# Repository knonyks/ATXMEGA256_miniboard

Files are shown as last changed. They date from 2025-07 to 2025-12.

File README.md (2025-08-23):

# ONYKS ATXMEGA256 Miniboard
Miniboard to prosta płytka deweloperska stworzona dla mikrokontrolera ATXMEGA256 przez KN ONYKS. Płytka zawiera możliwie minimalną liczbę elementów potrzebnych do zaczęcia programowania tego mikrokontrolera aby użytkownik miał pełną kontrolę nad swoim projektem.

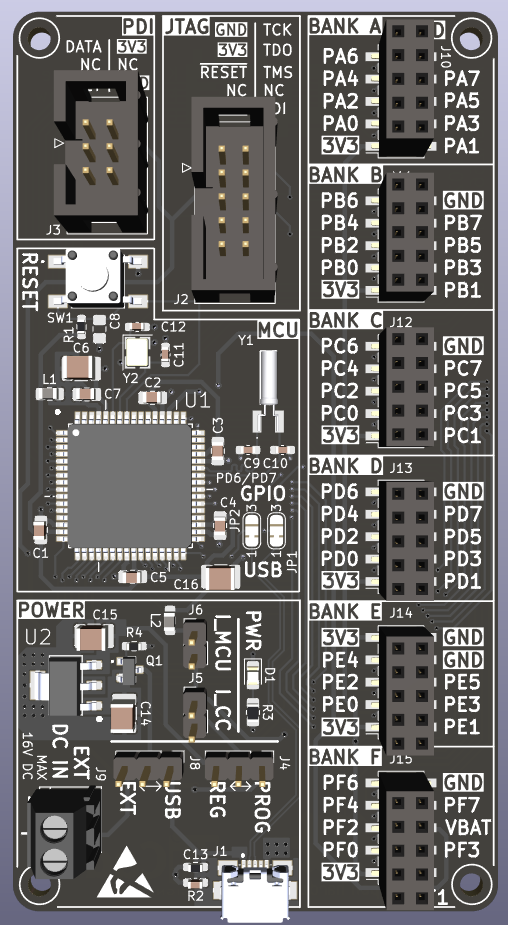
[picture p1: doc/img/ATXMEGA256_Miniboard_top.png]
Top

<br>
<br>
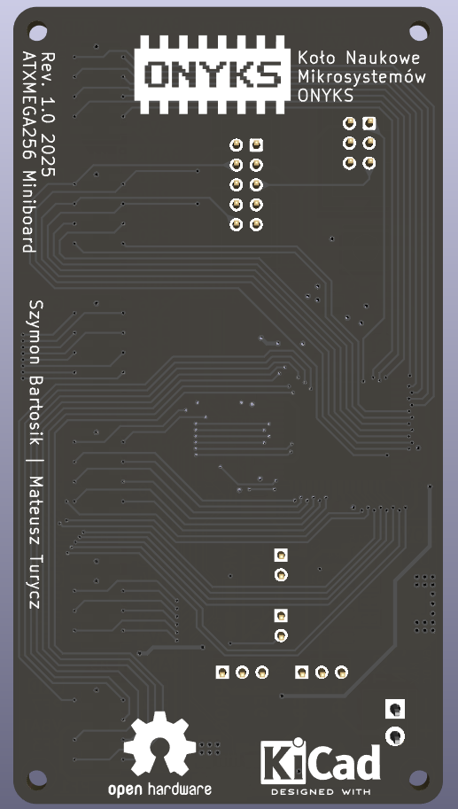
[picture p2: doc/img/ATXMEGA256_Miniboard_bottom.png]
Bottom


## TODO

- [x] Schemat połączeń MCU
- [x] Schemat sekcji zasilania
- [x] PCB
- [x] Dokumentacja - schematy, PCB, zdjęcia
- [ ] Dokumentacja - instrukcja obsługi
- [x] Dokumentacja - BOM
- [ ] Toolchain
- [x] Modele 3D
- [ ] Rysunek techniczny (poglądowy)

## Autorzy
Szymon Bartosik, Mateusz Turycz

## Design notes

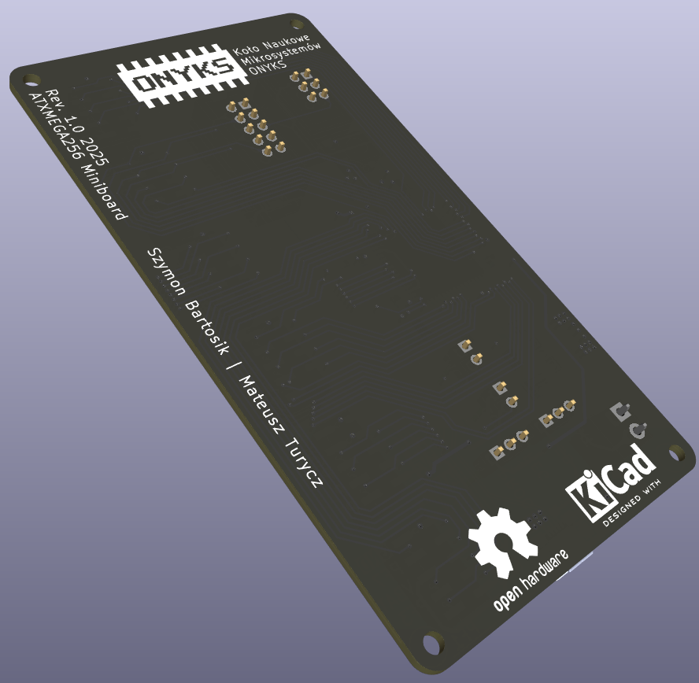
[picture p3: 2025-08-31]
doc/img/ATXMEGA256_Miniboard_bottom2.png

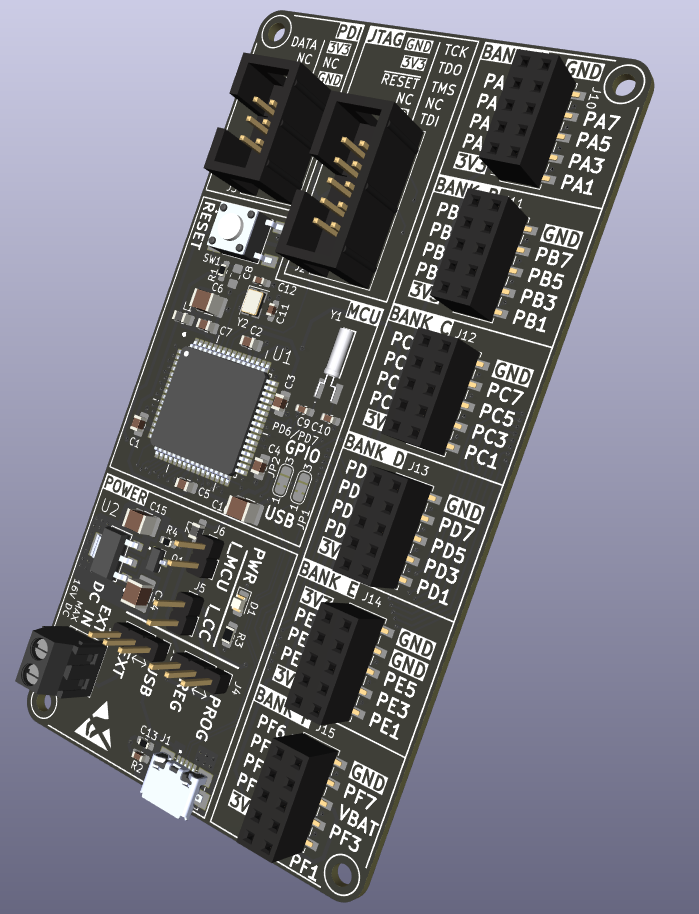
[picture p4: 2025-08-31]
doc/img/ATXMEGA256_Miniboard_top3.png

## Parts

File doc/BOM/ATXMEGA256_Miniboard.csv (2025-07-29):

Reference | Qty | Value | DNP | Footprint | Package | Part Number | Manufacturer
C1,C2,C3,C4,C5,C7,C8 | 7 | 100n | DNP | Capacitor_SMD:C_0805_2012Metric_Pad1.18x1.45mm_HandSolder | 0805 | C0805C104J4RACTU | KEMET
C6,C14,C15,C16 | 4 | 10u |  | Capacitor_SMD:C_1210_3225Metric_Pad1.33x2.70mm_HandSolder | 1210 | C1210C106K4RAC | KEMET
C9,C10 | 2 | 22p |  | Capacitor_SMD:C_0603_1608Metric_Pad1.08x0.95mm_HandSolder | 0603 | C0603C220J5GAC7867 | KEMET
C11,C12 | 2 | 12p |  | Capacitor_SMD:C_0603_1608Metric_Pad1.08x0.95mm_HandSolder | 0603 | C0603C120J5GACTU | KEMET
C13 | 1 | 4n7 |  | Capacitor_SMD:C_0603_1608Metric_Pad1.08x0.95mm_HandSolder | 0603 | C0603C472K3RACTU | KEMET
D1 | 1 | RED LED |  | LED_SMD:LED_0805_2012Metric_Pad1.15x1.40mm_HandSolder | 0805 | LTST-C171KRKT | LITEON
J1 | 1 | 10118192-0001LF |  | 10118192-0001LF:AMPHENOL_10118192-0001LF |  | 10118192-0001LF | Amphenol
J2 | 1 | 2x5 IDC Socket |  | Connector_IDC:IDC-Header_2x05_P2.54mm_Vertical |  | DS1013-10SSIB1-B-0 | CONNFLY
J3 | 1 | 2x3 IDC Socket |  | Connector_IDC:IDC-Header_2x03_P2.54mm_Vertical |  | T821106A1S100CEU | AMPHENOL COMMUNICATIONS SOLUTIONS
J4,J8 | 2 | 1x3 Goldpin Header |  | Connector_PinHeader_2.54mm:PinHeader_1x03_P2.54mm_Vertical |  | DS1021-1X3SF182-B | CONNFLY
J5,J6 | 2 | 1x2 Goldpin Header |  | Connector_PinHeader_2.54mm:PinHeader_1x02_P2.54mm_Vertical |  | DS1021-1X2SF162-B | CONNFLY
J9 | 1 | 1x2 Screw Terminal |  | DG381-3.5-02P-13-00AH:DG381-3.5-02P-13-00AH |  | DG381-3.5-02P-13-00AH | DEGSON ELECTRONICS
J10,J11,J12,J13,J14,J15 | 6 | 2x5 Goldpin Socket |  | Connector_PinSocket_2.54mm:PinSocket_2x05_P2.54mm_Vertical_SMD |  | ZL264-10DG | NINIGI
L1 | 1 | 2u2 |  | Inductor_SMD:L_0805_2012Metric_Pad1.15x1.40mm_HandSolder | 0805 | MLZ2012A2R2WT000 | TDK
L2 | 1 | 10u |  | Inductor_SMD:L_0805_2012Metric_Pad1.05x1.20mm_HandSolder | 0805 | MLZ2012M100HT000 | TDK
Q1 | 1 | MMFTP3334K |  | MMFTP3334K:TRANS_MMFTP3334K | SOT-23-3 | MMFTP3334K | DIOTEC SEMICONDUCTOR
R1,R4 | 2 | 10k |  | Resistor_SMD:R_0603_1608Metric_Pad0.98x0.95mm_HandSolder | 0603 | 0603SAJ0103T5E | ROYAL OHM
R2 | 1 | 1M |  | Resistor_SMD:R_0603_1608Metric_Pad0.98x0.95mm_HandSolder | 0603 | 0603SAJ0105T5E | ROYAL OHM
R3 | 1 | 240R |  | Resistor_SMD:R_0805_2012Metric_Pad1.20x1.40mm_HandSolder | 0805 | 0805S8J0241T5E | ROYAL OHM
SW1 | 1 | RESET |  | FSM2JSMAA:SW_SMD_2-1437565-8_4_4.50_6.00_6.00_5.00 |  | FSM2JSMAA | TE Connectivity
U1 | 1 | ATXMEGA256A3B-AU |  | ATXMega256A3B-AU:QFP80P1600X1600X120-64N | TQFP-64 | ATXMEGA256A3B-AU | Microchip
U2 | 1 | MCP1703A-3302E/DB |  | MCP1703A-3302E:SOT230P700X180-4N | SOT-223-3 | MCP1703A-3302E/DB | Microchip
Y1 | 1 | 32.768 kHz |  | LFXTAL025159:LFXTAL025159Reel |  | LFXTAL025159 | IQD FREQUENCY PRODUCTS
Y2 | 1 | 16 MHz |  | Crystal:Crystal_SMD_3225-4Pin_3.2x2.5mm | SMD_4Pin_3.2x2.5mm | LFXTAL053426 | IQD FREQUENCY PRODUCTS

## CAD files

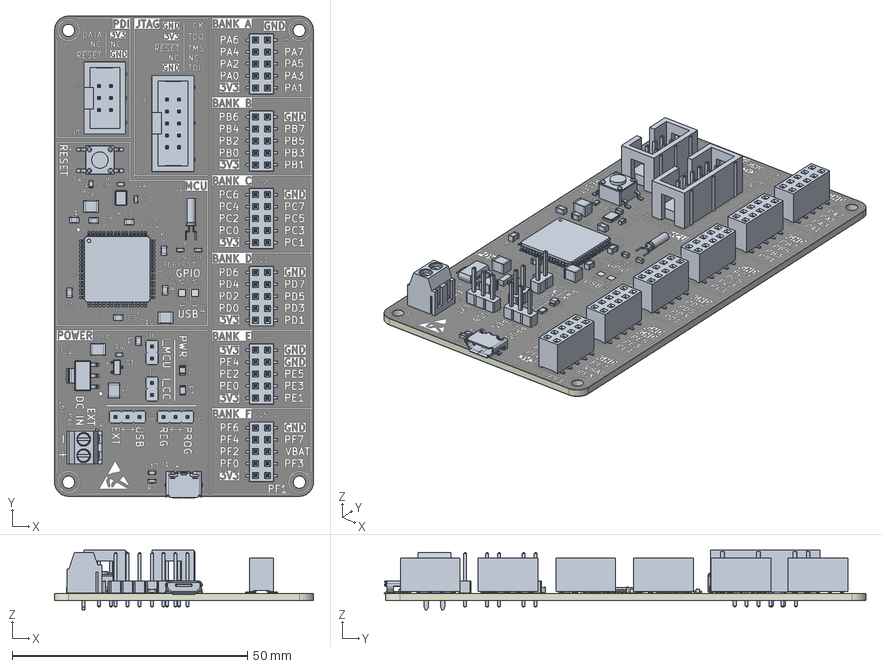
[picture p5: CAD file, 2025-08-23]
models/ATXMEGA256_Miniboard.step
55.0 x 102.4 x 12.7 mm
C_0603_1608Metric x 5
Circular Pattern 01
PinSocket_2x05_P2.54mm_Vertical_SMD x 6
C_0805_2012Metric x 6
PinHeader_1x02_P2.54mm_Vertical x 2
2N7002_2N7002
IDC-Header_2x05_P2.54mm_Vertical
R_0805_2012Metric
Body003 (Mirror #1)
Body003 (Mirror #3)
Body003 (Mirror #2)
10118192-0001LF
L_0805_2012Metric x 2
ATXMEGA256A3B-AU
LED_0805_2012Metric
C_1210_3225Metric x 4
IDC-Header_2x03_P2.54mm_Vertical
PinHeader_1x03_P2.54mm_Vertical x 2
R_0603_1608Metric x 3
MCP1703A-3302E_DB
DG381-3.5-02P-14-00A&Z(H)
Crystal_SMD_3225-4Pin_3.2x2.5mm
ATXMEGA256_Miniboard_silkscreen
ATXMEGA256_Miniboard_soldermask
ATXMEGA256_Miniboard_PCB

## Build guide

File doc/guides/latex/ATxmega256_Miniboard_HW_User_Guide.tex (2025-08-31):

\documentclass[11pt, hidelinks, a4paper]{report}

\usepackage{fancyhdr}							% Nagłówek
\usepackage[margin=1in]{geometry}				% Margines
\usepackage{wrapfig}
\usepackage{hyperref}							% Linki
\usepackage{fix-cm}
\usepackage{tikz}
\usepackage[document]{ragged2e}
\usepackage{graphicx}							% Grafiki
\usepackage[polish]{babel}						% Język polski
\usepackage[]{float}							% Umiesczanie grafik i tabel w dowolnych miejscach
\usepackage{pdfpages}							% Wklejanie stron pdf
\usepackage{tabularx}							% Tabele
\usepackage{array}
\usepackage{caption}							% Podpisy
\usepackage[T1]{fontenc}							% Czcionki
%\usepackage{subfig}								% Rysunki dzielone
\usepackage{subcaption}							% Podpisy mniejszych grafik
\usepackage{gensymb}							% Symbole
\usepackage{listings}							% Wklejanie kodu	
\usepackage[justification=centering]{caption}	% Centrowanie podpisów
\usepackage[default]{lato} % Czcionka
\usepackage{listings}
\usepackage{lastpage}
\usepackage{titlesec}
\usepackage[none]{hyphenat}
\usepackage{amsmath}
%\usepackage[table]{xcolor}
\usepackage{colortbl}
\usepackage{fmtcount}
\usepackage{xstring}
%----------------------------------------------------------------------------------------------------------------------------
% Definicje kolorów
\definecolor{tableheader}{HTML}{a6a6a6}
%----------------------------------------------------------------------------------------------------------------------------
% Ustawienia wklejanie kodu
\lstset{frame=tb,
	language=C,
	aboveskip=3mm,
	belowskip=3mm,
	showstringspaces=false,
	columns=flexible,
	basicstyle={\small\ttfamily},
	numbers=none,
	numberstyle=\tiny\color{gray},
	keywordstyle=\color{blue},
	commentstyle=\color{dkgreen},
	stringstyle=\color{mauve},
	breaklines=true,
	breakatwhitespace=true,
	tabsize=3
}
%----------------------------------------------------------------------------------------------------------------------------
% Polskie znaki w kodzie
\lstset{
	literate={ą}{{\k a}}1
	{Ą}{{\k A}}1
	{ż}{{\. z}}1
	{Ż}{{\. Z}}1
	{ź}{{\' z}}1
	{Ź}{{\' Z}}1
	{ć}{{\' c}}1
	{Ć}{{\' C}}1
	{ę}{{\k e}}1
	{Ę}{{\k E}}1
	{ó}{{\' o}}1
	{Ó}{{\' O}}1
	{ń}{{\' n}}1
	{Ń}{{\' N}}1
	{ś}{{\' s}}1
	{Ś}{{\' S}}1
	{ł}{{\l}}1
	{Ł}{{\L}}1
}
%----------------------------------------------------------------------------------------------------------------------------
% Ścieżka do grafik
\graphicspath{{../../img/}}
%----------------------------------------------------------------------------------------------------------------------------
% Definicje
\def\companyname{Koło Naukowe Mikrosystemów ONYKS}
\def\revision{1.0}
\def\docnumber{UGHW1}
\def\lang{PL}
\def\repolink{github.com/knonyks/ATXMEGA256_miniboard}

\def\headerheight{1cm}
%----------------------------------------------------------------------------------------------------------------------------
% Nagłówek
\pagestyle{fancy}
\setlength{\headheight}{\headerheight}
\renewcommand{\headrulewidth}{0pt}

\fancyhf{}
\fancyhead[R]{
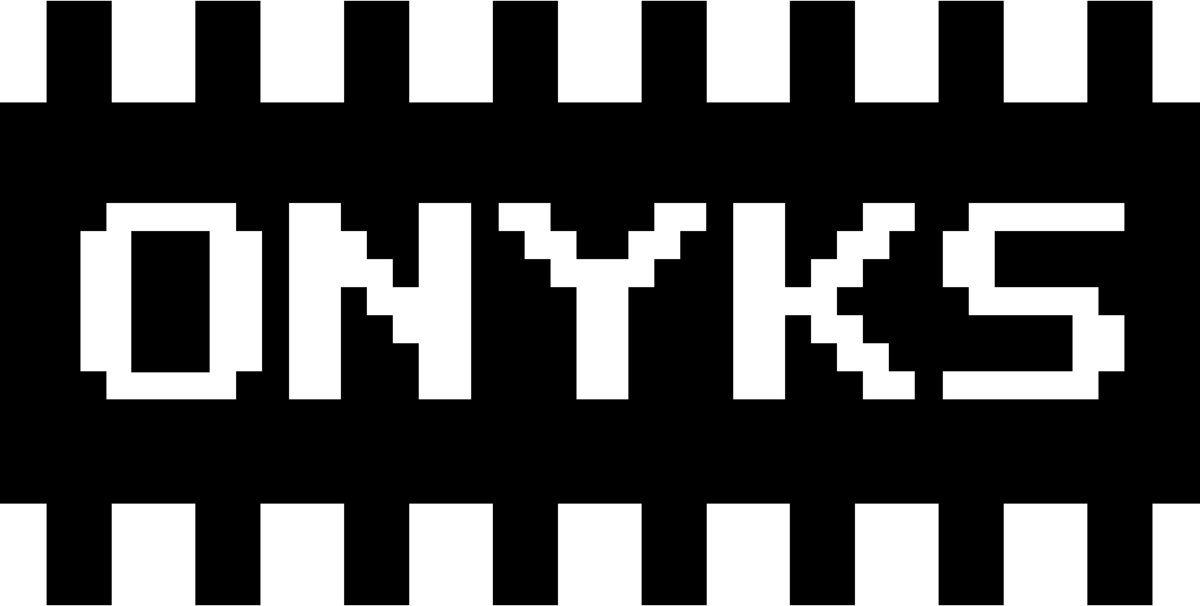
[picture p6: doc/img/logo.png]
	
}
\fancyhead[L]{\leftmark}
%----------------------------------------------------------------------------------------------------------------------------
% Stopka
\fancyfoot[L]{\docnumber(\lang) \space Rev. \space \revision, \space \today \hfill \thepage \space\space /  \space \pageref{LastPage}}
%----------------------------------------------------------------------------------------------------------------------------
% Redefinicja stylu plain
\fancypagestyle{plain}{
	\fancyhf{}
	\fancyhead[R]{
		
	}
	\fancyhead[L]{\leftmark}
	\fancyfoot[L]{\docnumber(\lang) \space Rev.\space \revision, \space \today \hfill \thepage \space\space / \space \pageref{LastPage}}
}
%----------------------------------------------------------------------------------------------------------------------------
% Wyłączenie dzielenia wyrazów
\tolerance=1
\emergencystretch=\maxdimen
\hyphenpenalty=1000
\hbadness=1000
%----------------------------------------------------------------------------------------------------------------------------
% Styl rozdziału
\definecolor{onyks-gray}{gray}{0.82}
\definecolor{onyks-red}{HTML}{e50000}
\definecolor{onyks-white}{HTML}{eeeeee}
\titleformat{\chapter}[block]
{\normalfont\Huge\bfseries}
{\colorbox{onyks-gray}{\parbox{\dimexpr0.07\textwidth\relax}{\thechapter}}}
{0.5em}
{\textcolor{onyks-red}{|} \hspace{0.5em}}
%{\thechapter}{0.5em}
%{\textcolor{red}{|} \hspace{0.5em}}
\titlespacing*{\chapter}{0pt}{0pt}{30pt}
%----------------------------------------------------------------------------------------------------------------------------
% Numerowanie stron
\pagenumbering{arabic}
%----------------------------------------------------------------------------------------------------------------------------
% Ustawienia tabel
\renewcommand{\arraystretch}{1.2}
%----------------------------------------------------------------------------------------------------------------------------
\begin{document}
	% Strona tytułowa
	\label{Title}
	\begin{titlepage}
		
		\thispagestyle{empty}
		
		\vspace*{1cm}
		
		\begin{FlushLeft}
			\textbf{\Huge \textcolor{onyks-red}{|}
				ATxmega256 Miniboard\\
				\vspace{10pt}
				\huge Warstwa sprzętowa}\\
			\vspace*{1cm}
			\LARGE Przewodnik użytkownika\\
			\large \docnumber (\lang) \space Rev. \revision\\
			\today
		\end{FlushLeft}
		
		\vfill
		
		\begin{Center}
			\\
			\vspace*{1cm}
			\Large \companyname
		\end{Center}
		
		\vspace*{3cm}

	\end{titlepage}
	\setcounter{page}{2}
	\setcounter{tocdepth}{3}
	\tableofcontents
	
	\justifying
	\sloppy
	
	\chapter{Wstęp}
	Płytka ATxmega256 Miniboard została przygotowana przez KN ONYKS jako projekt edukacyjny mający na celu naukę programowania i projektowania układów z mikrokontroleremi z serii ATxmega256.
	\\
	Materiały dotyczące projektu można znaleźć w oficjalnym repozytorium Github KN ONYKS \textcolor{blue}{\url{\repolink}}.
	\\
	\\
	Ten dokument jest przewodnikiem po części sprzętowej płytki rozwojowej. Instrukcje dotyczące środowiska programowania i debugowania znajdują się w innym dokumencie.
	
	\begin{Center}
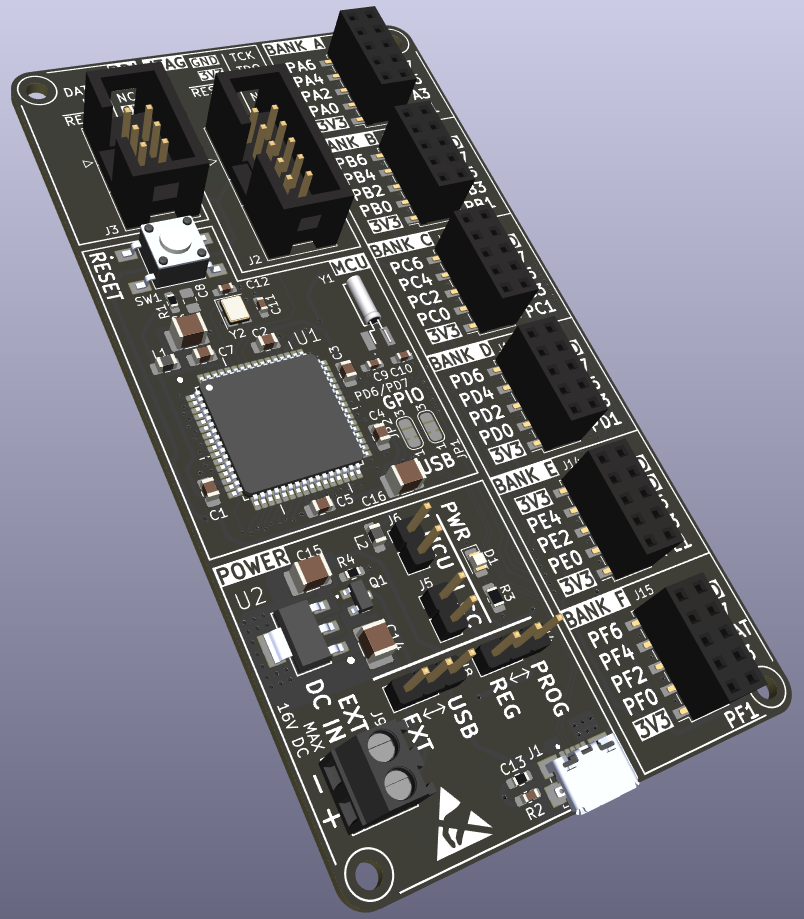
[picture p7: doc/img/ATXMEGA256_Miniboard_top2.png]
		\\
	\end{Center}

	\chapter{Konfiguracja połączeń}
	Płytka posiada wiele możliwości konfiguracji zasilania oraz interfejsów. W układzie znajduje się tylko absolutne minimum elementów potrzebnych do poprawnego funkcjonowania mikrokontrolera aby użytkownik miał pełną kontrolę na interfejsami, GPIO i zegarami w swoim projekcie.
	
	\section{Opcje zasilania}
	Układ działa poprawnie z nominalnym poziomem napięcia 3,3 V. Istnieje kilka możliwości zasilania płytki:
	\begin{itemize}
		\item Zewnętrzne źródło (EXT)
		\item Micro USB
		\item Zasilanie 3,3 V przez programator
	\end{itemize} 

	\begin{figure}[H]
		\centering
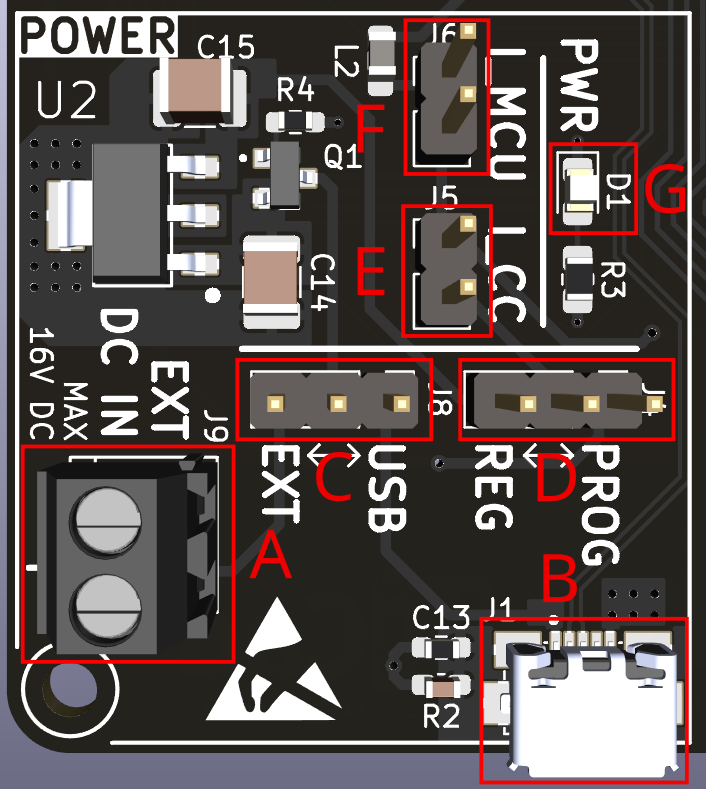
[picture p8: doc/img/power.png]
		
		\caption{Sekcja zasilania}
	\end{figure}
	\newpage
	Objaśnienia oznaczeń:
	\begin{itemize}
		\item A - złącze śrubowe do podłączenia napięcia zewnętrznego EXT
		\item B - złącze micro USB
		\item C - przełącznik źródła napięcia regulatora 3,3 V:\\ pozycja EXT - napięcie ze złącza śrubowego,\\ pozycja USB - 5 V z micro USB
		\item D - przełącznik źródła 3,3 V:\\ pozycja REG - regulator,\\ pozycja PROG - zasilanie z programatora
		\item E - punkt pomiaru prądu całego układu (zwarty lub podłączony amperomierz)
		\item F - punkt pomiaru prądu samego mikrokontrolera (zwarty lub podłączony amperomierz)
		\item G - LED informujący o podłączonym zasilaniu 3,3 V
	\end{itemize} 

		\subsection{Zewnętrzne źródło (EXT)}
			Zewnętrzne źródło napięcia można podłączyć (zwracając uwagę na polaryzację) przez złącze śrubowe. Minimalne napięcie przy którym układ będzie działać poprawnie to około 4,3 V, a maksymalne 16 V. Ograniczenia wynikają z zastosowanego regulatora napięcia. W przypadku wyższych napięć i dużego poboru prądu można spodziewać się automatycznego wyłączenia regulatora przez osiągnięcie zbyt wysokiej temperatury.
		\subsection{Zasilanie 3,3 V przez programator}
			Układ może być zasilany bezpośrednio z napięcia 3,3 V pochodzącego z programatora podłączonego do odpowiednich złączy programujących. Należy wtedy zewrzeć kontakt środkowy i oznaczony napisem PROG na złączu oznaczonym na rysunku jako D. Taka konfiguracja odłącza wyjście regulatora.
			\\
			Niektóre programatory wymagają podłączenia do napięcia zasilania mikrokontrolera aby dopasować poziomy logiczne ale same nie zasilają układu (przykład: Microchip Pickit Basic w konfiguracji JTAG). Jeżeli układ jest zasilany z innego źródła niż programator to kontakty zasilania 3V3 na złączach programujących będą odłączone (patrz: schemat).
		
	\section{Interfejsy programowania}
		Mikrokontrolery z rodziny ATxmega256 posiadają 2 interfejsy programowania i debugowania:
		\begin{itemize}
			\item PDI (Program and Debug Interface) - własny interfejs Microchip
			\item JTAG (Joined Test and Action Group)
		\end{itemize}
		Interfejs PDI jest zawsze dostępny przez dedykowane nóżki. Interfejs JTAG jest fabrycznie włączony i dostępny przez część pinów GPIO (patrz: schemat). Za pomocą bitów konfiguracyjnych (Fuse Bits) istnieje możliwość jego wyłączenia, a także konfiguracji ID.
		\\
		\\
		\textbf{Należy uważać na GPIO opisane na schemacie, które są współdzielone z JTAG. Nieodpowiednie podłączenie może doprowadzić do uszkodzenia interfejsu lub programatora.} 
		
		\begin{figure}[H]
			\centering
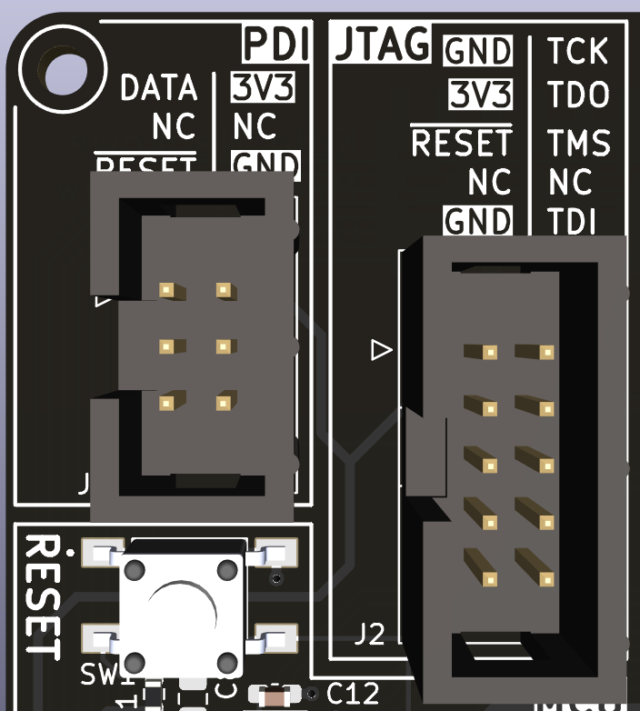
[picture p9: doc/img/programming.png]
			
			\caption{Sekcja programowania}
		\end{figure}
	
	\section{Zegary}
		Mikrokotrolery z rodziny ATxmega256 posiadają wiele opcji ustawień zegara. Na płytce znajduje się kryształ 16 MHz oznaczony na rysunku \ref{mcu} symbolem I. Dodatkowo podłączony jest też kryształ RTC 32,768 kHz oznaczony symbolem J. W przypadku potrzeby ręcznego resetu mikrokotrolera, znajduje się przy nim przycisk RESET oznaczony symbolem H.
		\begin{figure}[H]
			\centering
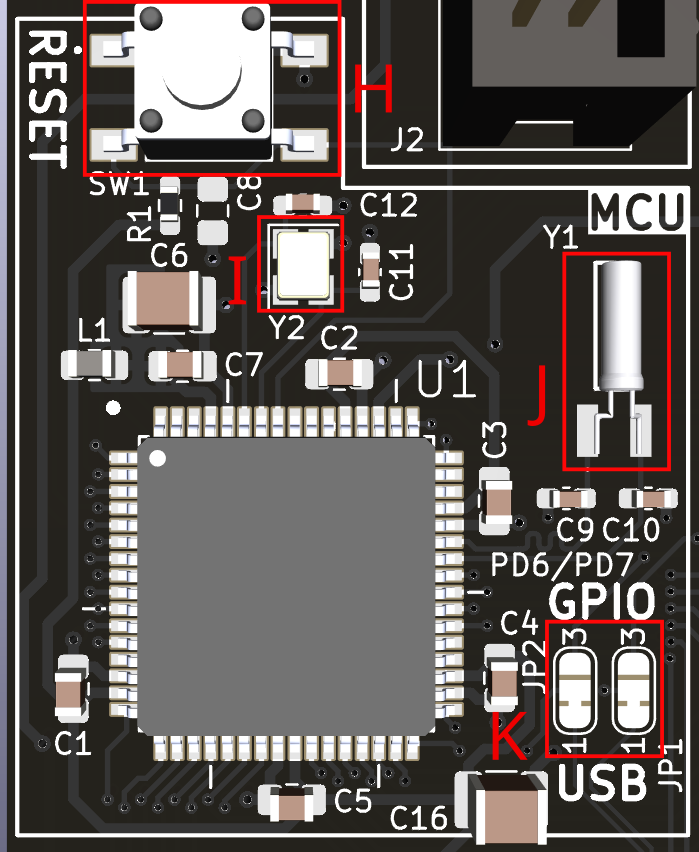
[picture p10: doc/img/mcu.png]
			
			\caption{Sekcja mikrokontrolera}
			\label{mcu}
		\end{figure}
	\section{USB}
		Złącze micro USB może być wykorzystane również do przesyłu danych dzięki wbudowanemu interfejsowi USB mikrokontrolera. Interfejs USB jest współdzielony z niektórymi GPIO (patrz:schemat). Złącze K z rysunku \ref{mcu} służy do konfigurowania połączenia USB. Domyślnie do mikrokontrolera podłączona jest linia danych USB, a wyprowadzenia GPIO są odłączone. Istnieje możliwość odłączenia linii danych i podłączenia do wyprowadzeń GPIO. W tym celu należy przeciąć ścieżkę pomiędzy polami lutowniczymi 1 (USB) i 2 (środkowe), a następnie zmostkowanie cyną pól 2 i 3 (GPIO). Należy to zrobić w obydwu złączach.
	
	\chapter{Dodatek A: Schemat układu}
		\includepdf[pages={-},angle=270]{../../schematics/ATXMEGA256_Miniboard.pdf}
	\chapter{Dodatek B: Schemat PCB}
		\includepdf[pages={-},angle=270]{../../pcb/ATXMEGA256_Miniboard_PCB.pdf}
\end{document}

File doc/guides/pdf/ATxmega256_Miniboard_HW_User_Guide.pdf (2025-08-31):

# | ATxmega256 Miniboard

# Warstwa sprzętowa

## Przewodnik użytkownika

UGHW1(PL) Rev. 1.0
31 sierpnia 2025

## Koło Naukowe Mikrosystemów ONYKS

SPIS TREŚCI

# | Spis treści

1 Wstęp | 3
2 Konfiguracja połączeń | 4
3 Dodatek A: Schemat układu | 8
4 Dodatek B: Schemat PCB | 12
UGHW1(PL) Rev. 1.0, 31 sierpnia 2025 | 2 / 13

ROZDZIAŁ 1. WSTĘP

# 1 | Wstęp

Płytka ATxmega256 Miniboard została przygotowana przez KN ONYKS jako projekt edukacyjny mający na celu naukę programowania i projektowania układów z mikrokontroleremi z serii ATxmega256.
Materiały dotyczące projektu można znaleźć w oficjalnym repozytorium Github KN ONYKS
github.com/knonyks/ATXMEGA256_miniboard.

Ten dokument jest przewodnikiem po części sprzętowej płytki rozwojowej. Instrukcje dotyczące środowiska programowania i debugowania znajdują się w innym dokumencie.

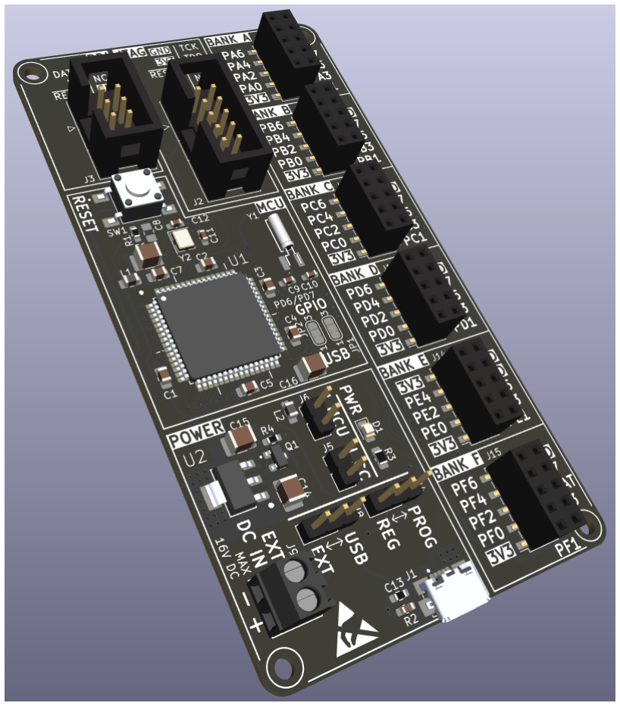
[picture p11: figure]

ROZDZIAŁ 2. KONFIGURACJA POŁĄCZEŃ

# 2 | Konfiguracja połączeń

Płytka posiada wiele możliwości konfiguracji zasilania oraz interfejsów. W układzie znajduje się tylko absolutne minimum elementów potrzebnych do poprawnego funkcjonowania mikrokontrolera aby użytkownik miał pełną kontrolę na interfejsami, GPIO i zegarami w swoim projekcie.

## 2.1 Opcje zasilania

Układ działa poprawnie z nominalnym poziomem napięcia 3,3 V. Istnieje kilka możliwości zasilania płytki:

- Zewnętrzne źródło (EXT)
- Micro USB
- Zasilanie 3,3 V przez programator


Rysunek 2.1: Sekcja zasilania

ROZDZIAŁ 2. KONFIGURACJA POŁĄCZEŃ

Objaśnienia oznaczeń:

- A - złącze śrubowe do podłączenia napięcia zewnętrznego EXT
- B - złącze micro USB
- C - przełącznik źródła napięcia regulatora 3,3 V:
pozycja EXT - napięcie ze złącza śrubowego, pozycja USB - 5 V z micro USB
- D - przełącznik źródła 3,3 V:
pozycja REG - regulator,
pozycja PROG - zasilanie z programatora
- E - punkt pomiaru prądu całego układu (zwarty lub podłączony amperomierz)
- F - punkt pomiaru prądu samego mikrokontrolera (zwarty lub podłączony amperomierz)
- G - LED informujący o podłączonym zasilaniu 3,3 V

### 2.1.1 Zewnętrzne źródło (EXT)

Zewnętrzne źródło napięcia można podłączyć (zwracając uwagę na polaryzację) przez złącze śrubowe. Minimalne napięcie przy którym układ będzie działać poprawnie to około 4,3 V, a maksymalne 16 V. Ograniczenia wynikają z zastosowanego regulatora napięcia. W przypadku wyższych napięć i dużego poboru prądu można spodziewać się automatycznego wyłączenia regulatora przez osiągnięcie zbyt wysokiej temperatury.

### 2.1.2 Zasilanie 3,3 V przez programator

Układ może być zasilany bezpośrednio z napięcia 3,3 V pochodzącego z programatora podłączonego do odpowiednich złączy programujących. Należy wtedy zewrzeć kontakt środkowy i oznaczony napisem PROG na złączu oznaczonym na rysunku jako D. Taka konfiguracja odłącza wyjście regulatora.
Niektóre programatorywymagają podłączenia do napięcia zasilania mikrokontrolera aby dopasować poziomy logiczne ale same nie zasilają układu (przykład: Microchip Pickit Basic w konfiguracji JTAG). Jeżeli układ jest zasilany z innego źródła niż programator to kontakty zasilania 3V3 na złączach programujących będą odłączone (patrz: schemat).

## 2.2 Interfejsy programowania

Mikrokontrolery z rodziny ATxmega256 posiadają 2 interfejsy programowania i debugowania:

- PDI (Program and Debug Interface) - własny interfejs Microchip
- JTAG (Joined Test and Action Group)

Interfejs PDI jest zawsze dostępny przez dedykowane nóżki. Interfejs JTAG jest fabrycznie włączony i dostępny przez część pinów GPIO (patrz: schemat). Za pomocą bitów konfiguracyjnych (Fuse Bits) istnieje możliwość jego wyłączenia, a także konfiguracji ID.

Należy uważać na GPIO opisane na schemacie, które są współdzielone z JTAG. Nieodpowiednie podłączenie może doprowadzić do uszkodzenia interfejsu lub programatora.

ROZDZIAŁ 2. KONFIGURACJA POŁĄCZEŃ

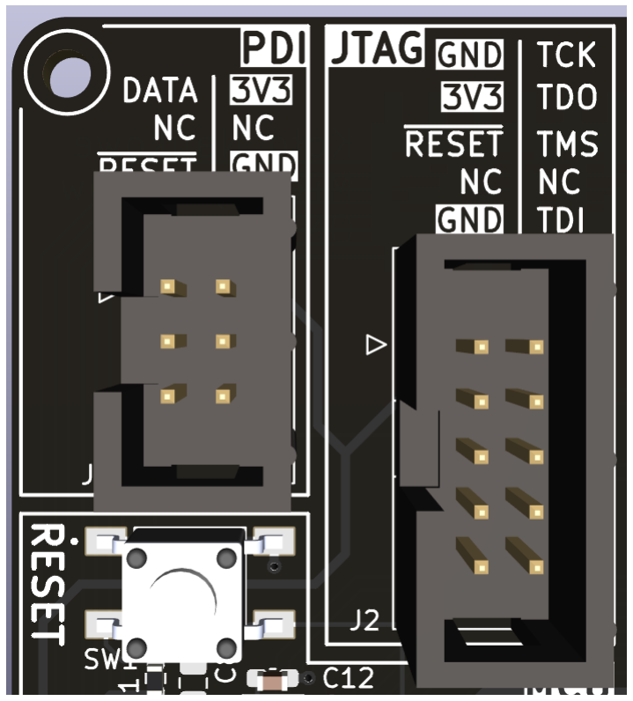
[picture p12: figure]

Rysunek 2.2: Sekcja programowania

## 2.3 Zegary

Mikrokotrolery z rodziny ATxmega256 posiadają wiele opcji ustawień zegara. Na płytce znajduje się kryształ 16 MHz oznaczony na rysunku 2.3 symbolem I. Dodatkowo podłączony jest też kryształ RTC 32,768 kHz oznaczony symbolem J. W przypadku potrzeby ręcznego resetu mikrokotrolera, znajduje się przy nim przycisk RESET oznaczony symbolem H.

ROZDZIAŁ 2. KONFIGURACJA POŁĄCZEŃ

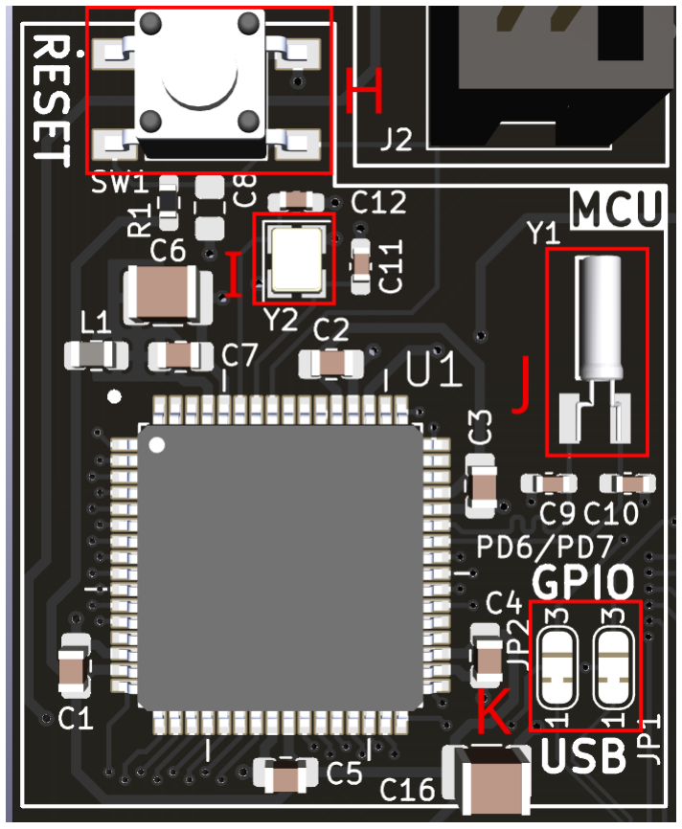
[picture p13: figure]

Rysunek 2.3: Sekcja mikrokontrolera

## 2.4 USB

Złącze micro USB może być wykorzystane również do przesyłu danych dzięki wbudowanemu interfejsowi USB mikrokontrolera. Interfejs USB jest współdzielony z niektórymi GPIO (patrz:schemat). Złącze K z rysunku 2.3 służy do konfigurowania połączenia USB. Domyślnie do mikrokontrolera podłączona jest linia danych USB, a wyprowadzenia GPIO są odłączone. Istnieje możliwość odłączenia linii danych i podłączenia do wyprowadzeń GPIO. W tym celu należy przeciąć ścieżkę pomiędzy polami lutowniczymi 1 (USB) i 2 (środkowe), a następnie zmostkowanie cyną pól 2 i 3 (GPIO). Należy to zrobić w obydwu złączach.

ROZDZIAŁ 3. DODATEK A: SCHEMAT UKŁADU

# 3 | Dodatek A: Schemat układu

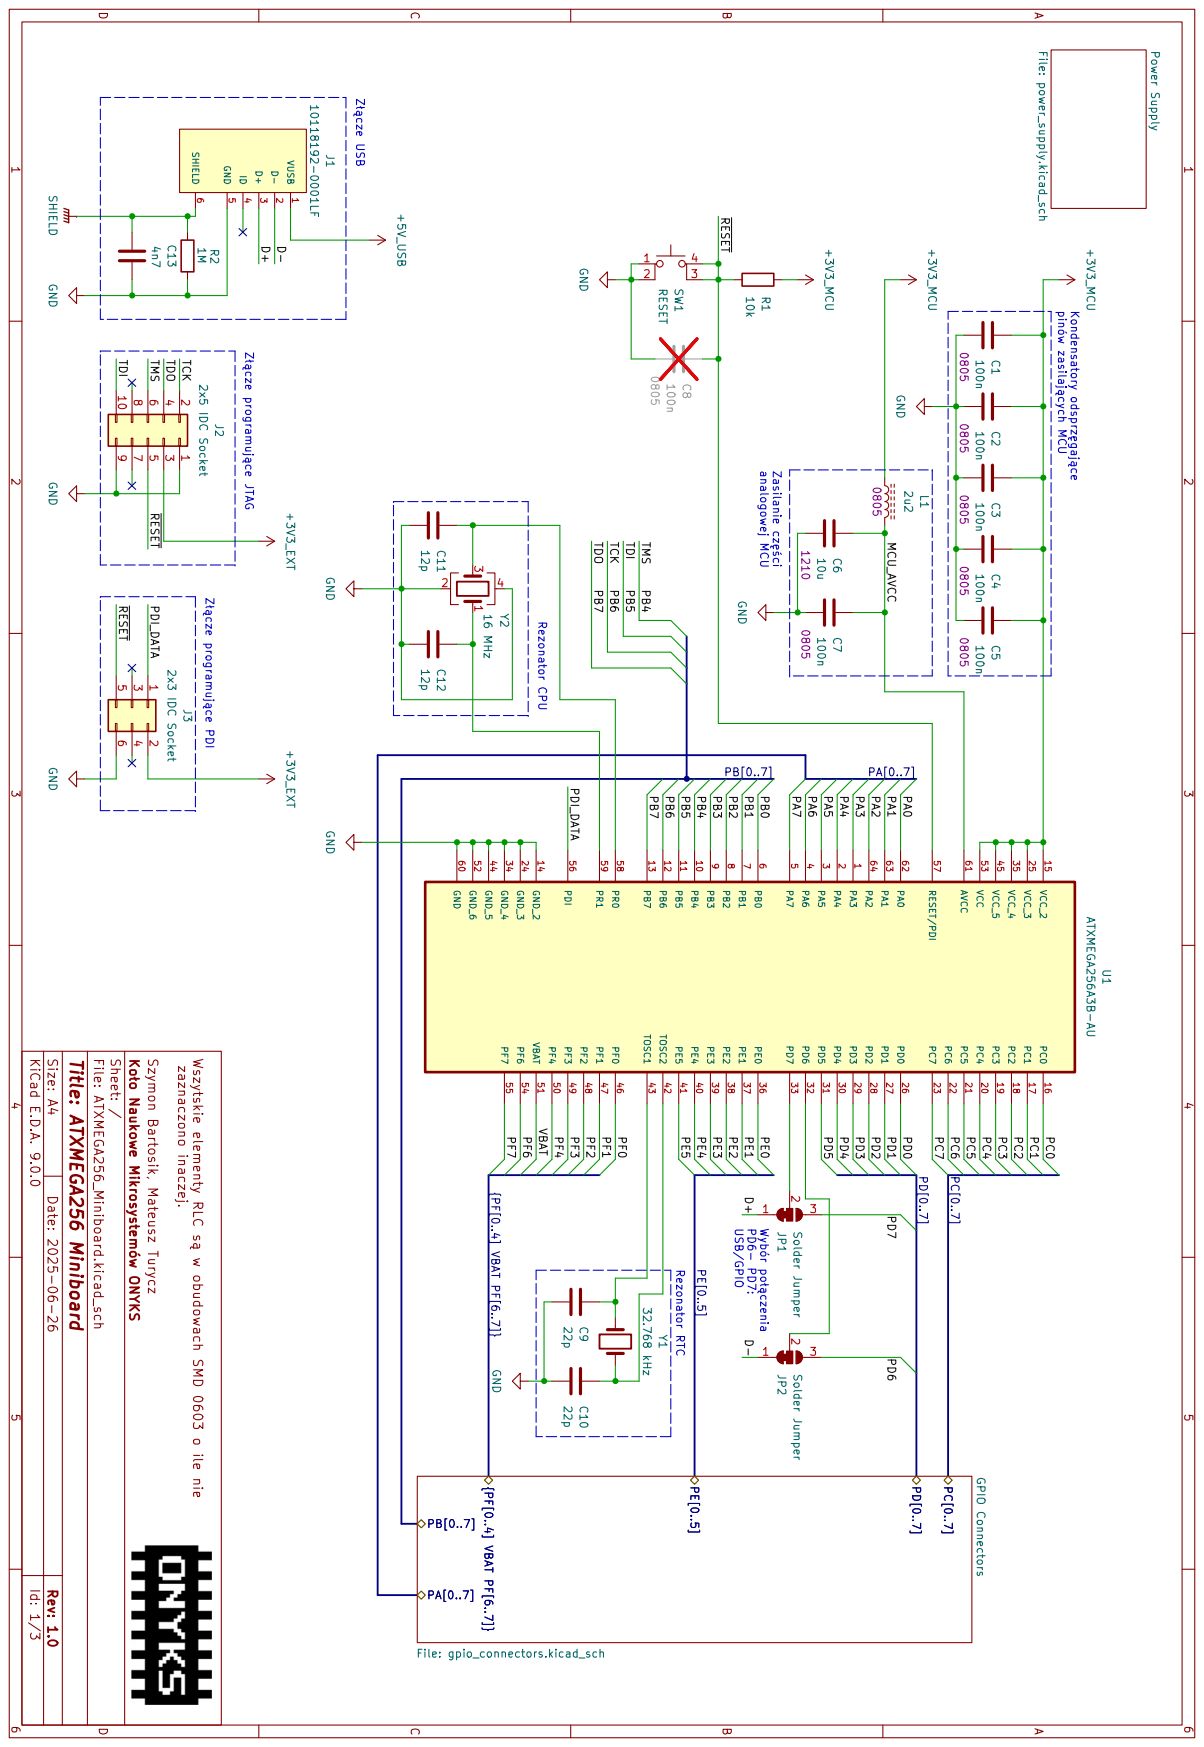
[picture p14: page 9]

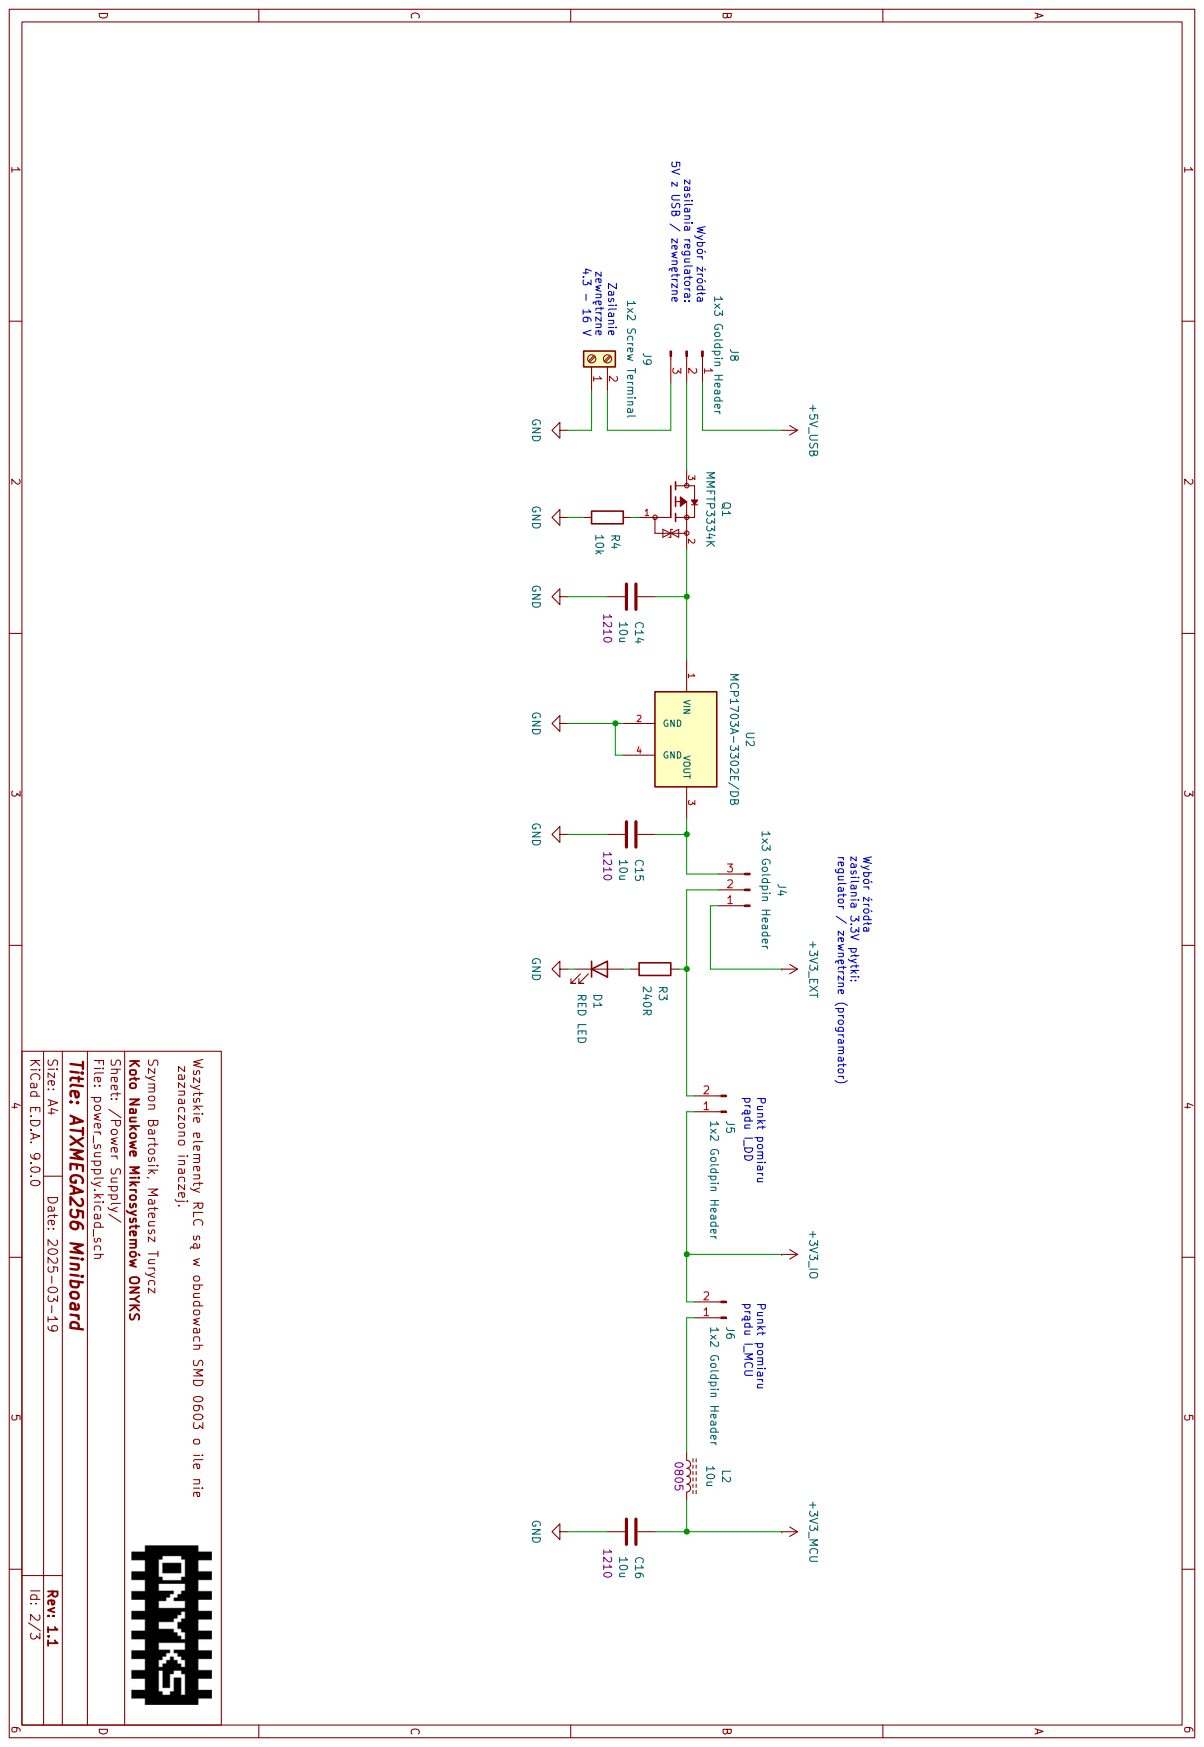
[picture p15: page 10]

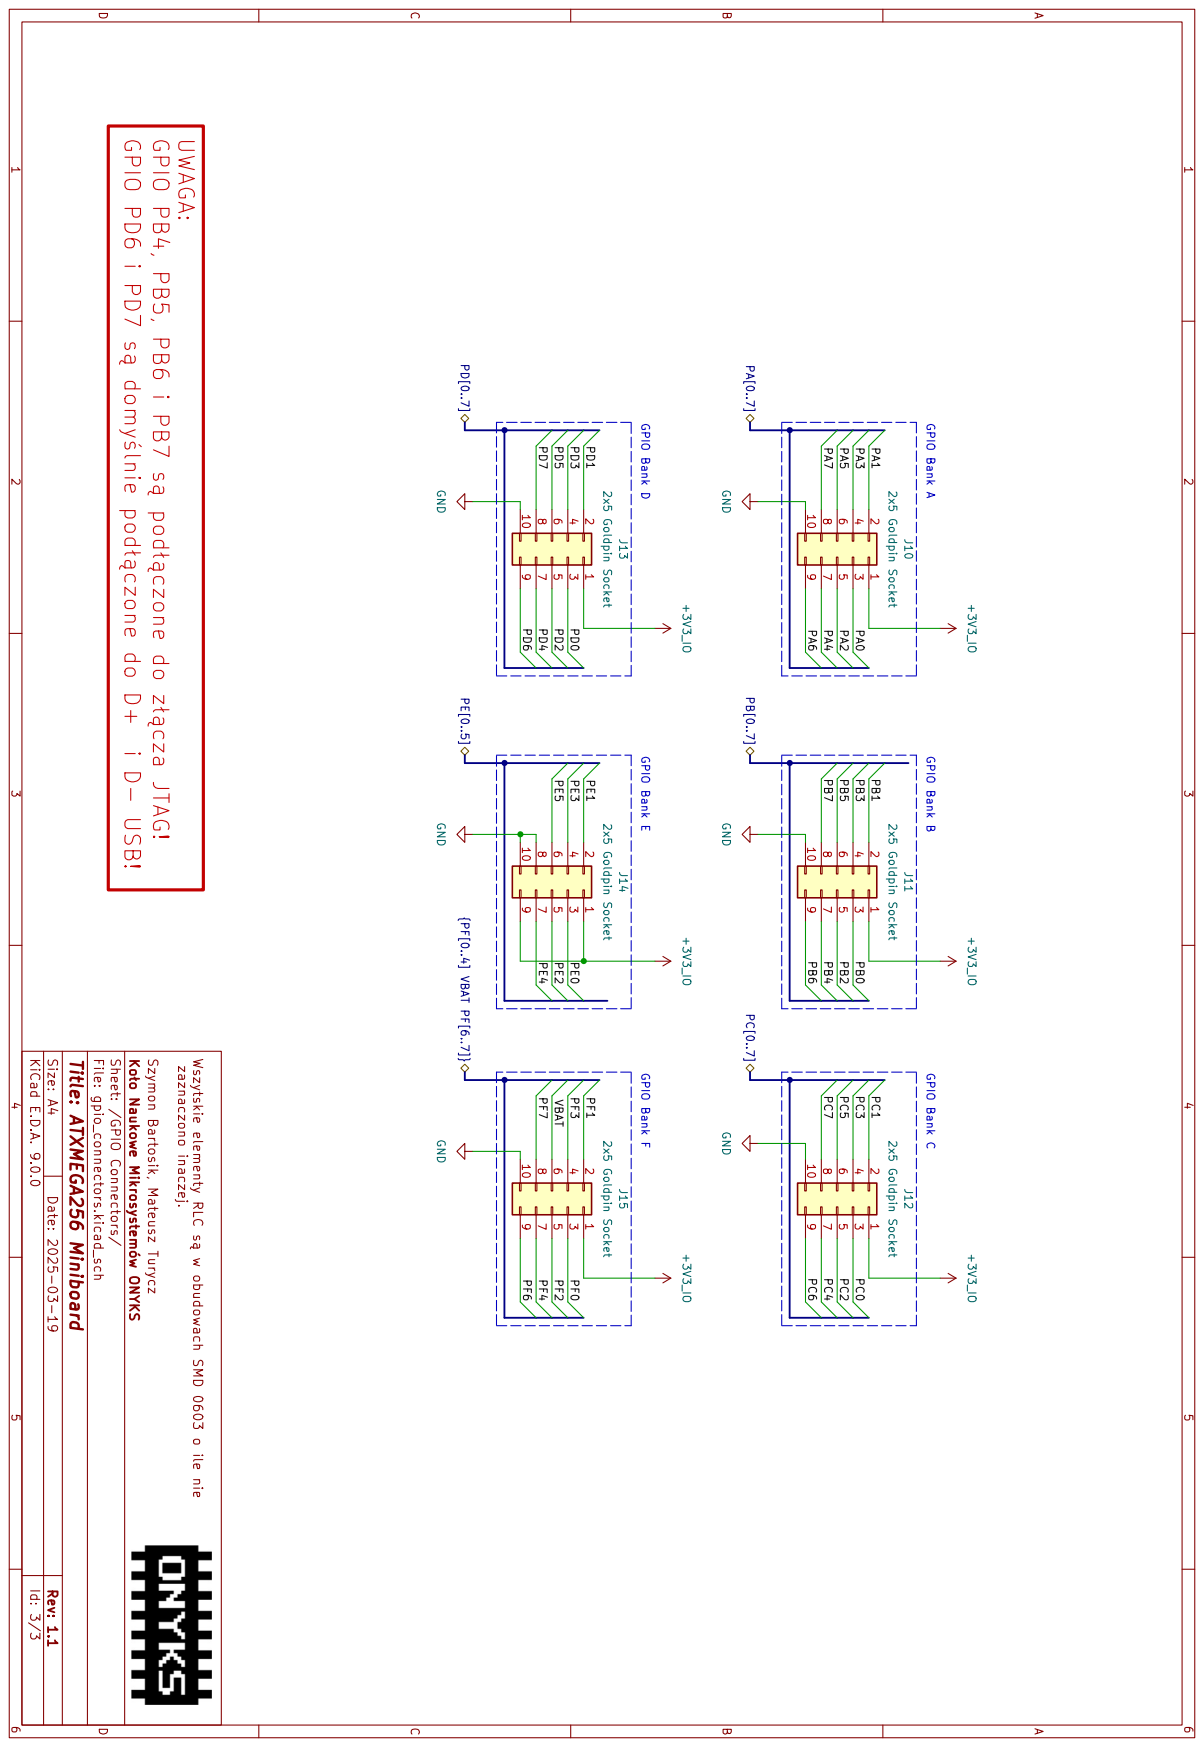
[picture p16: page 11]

ROZDZIAŁ 4. DODATEK B: SCHEMAT PCB

# 4 | Dodatek B: Schemat PCB

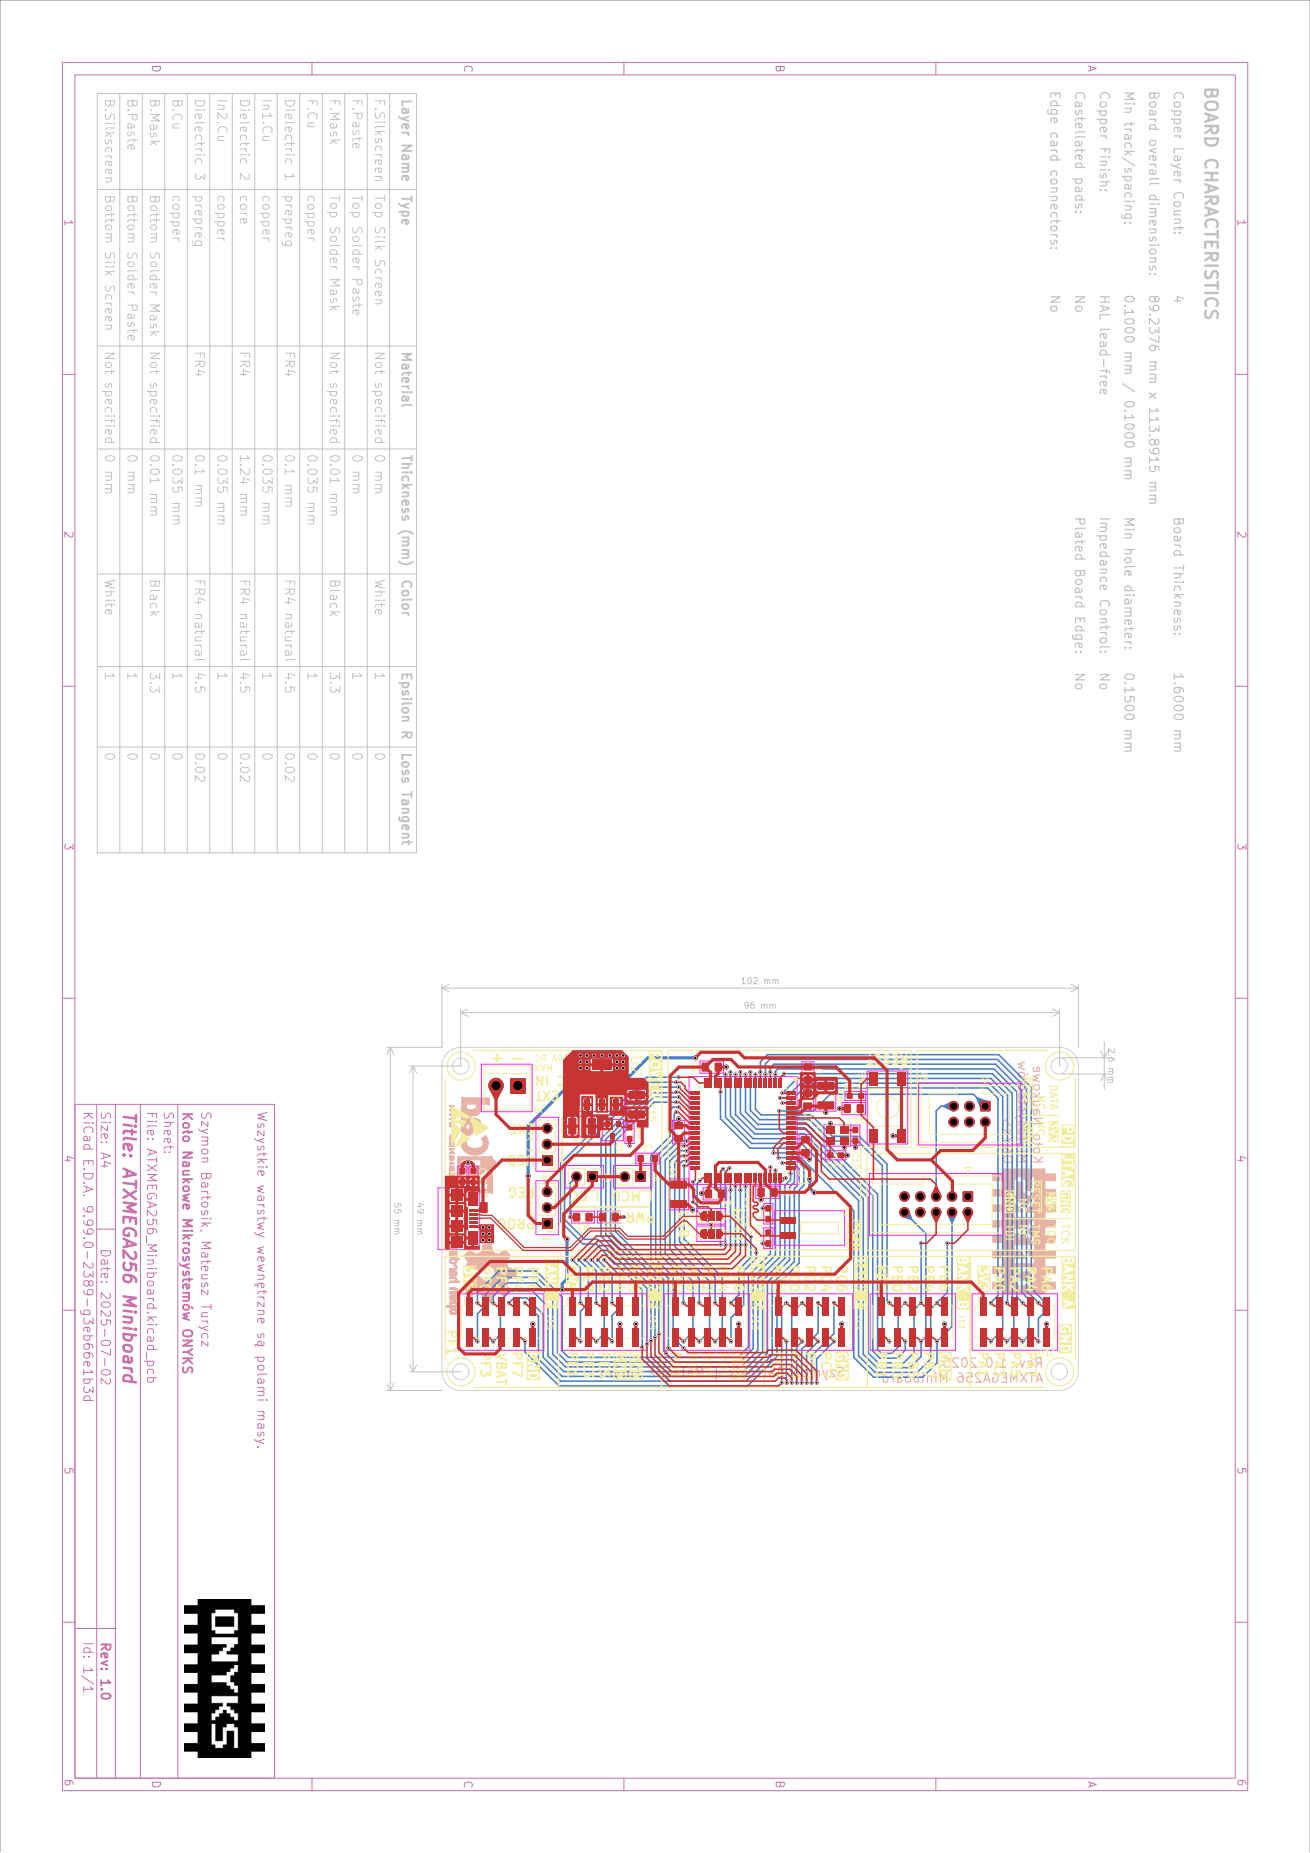
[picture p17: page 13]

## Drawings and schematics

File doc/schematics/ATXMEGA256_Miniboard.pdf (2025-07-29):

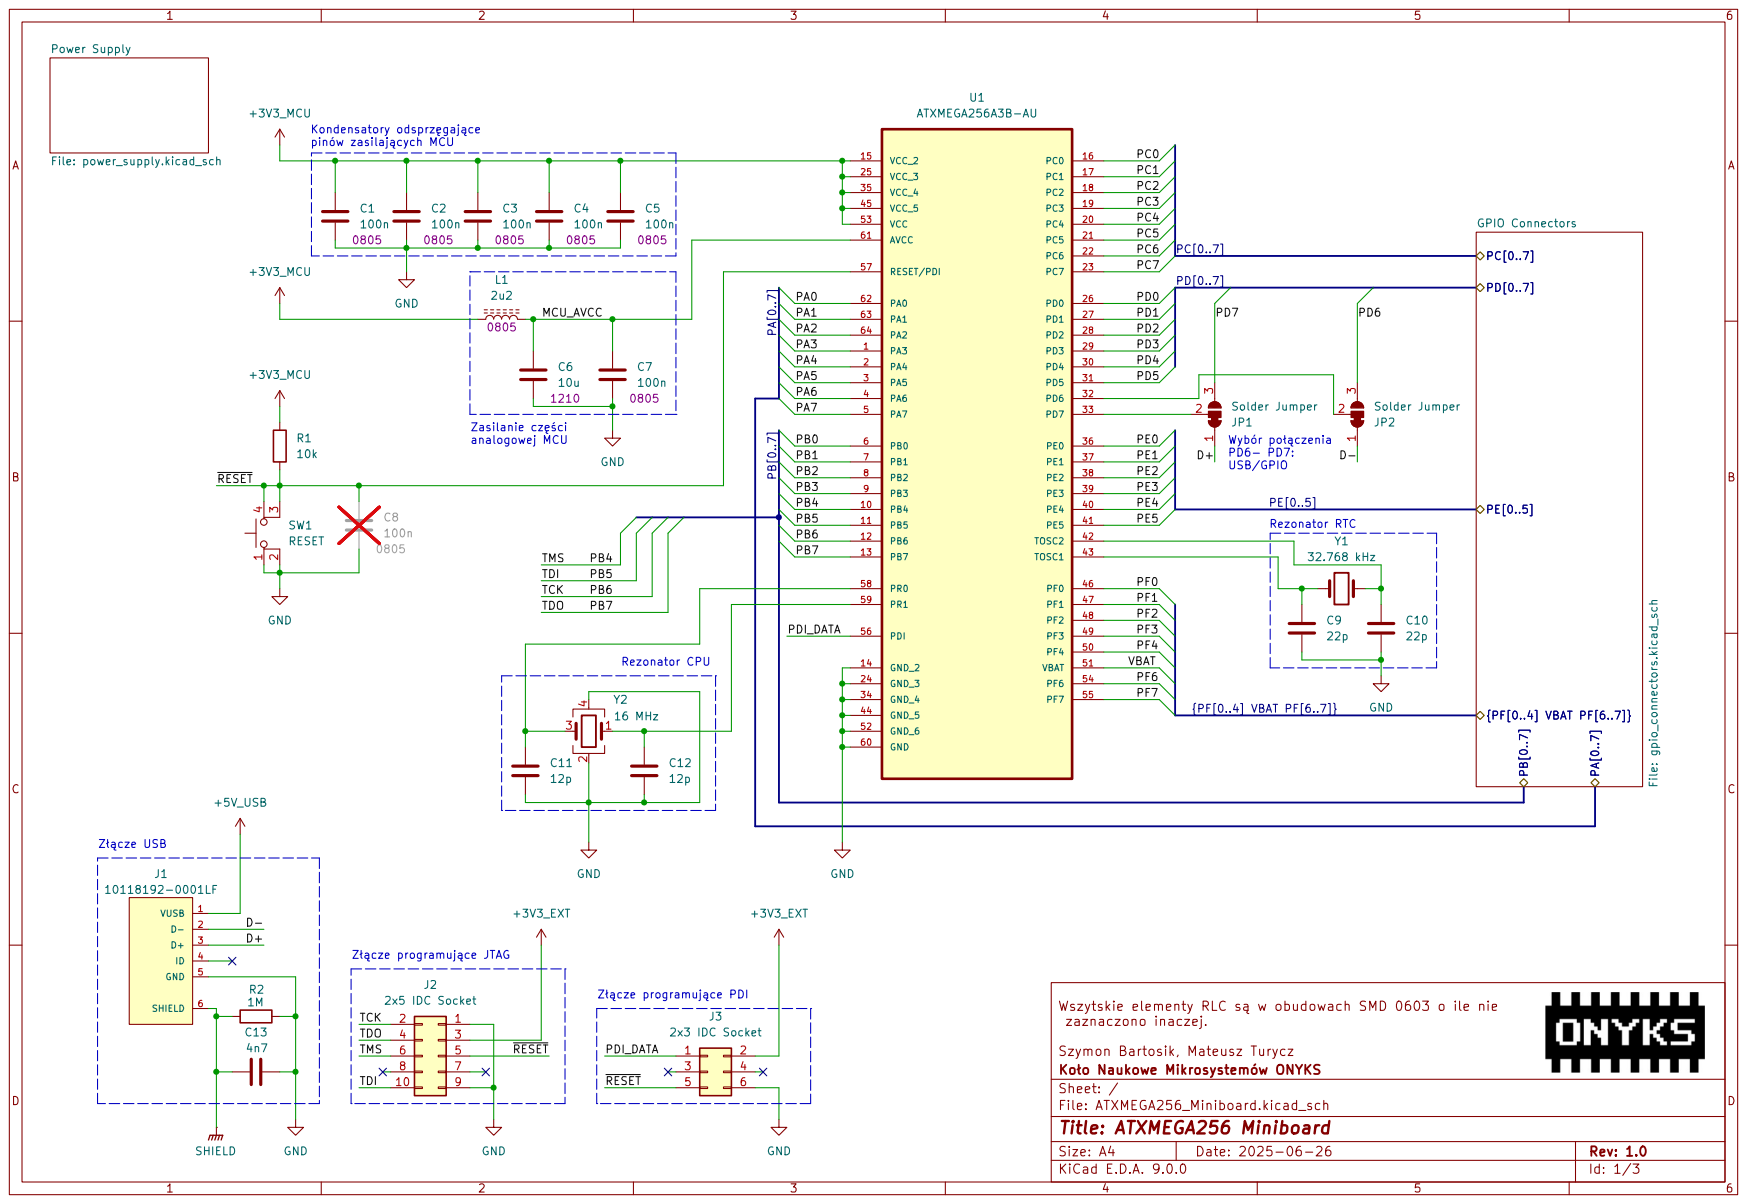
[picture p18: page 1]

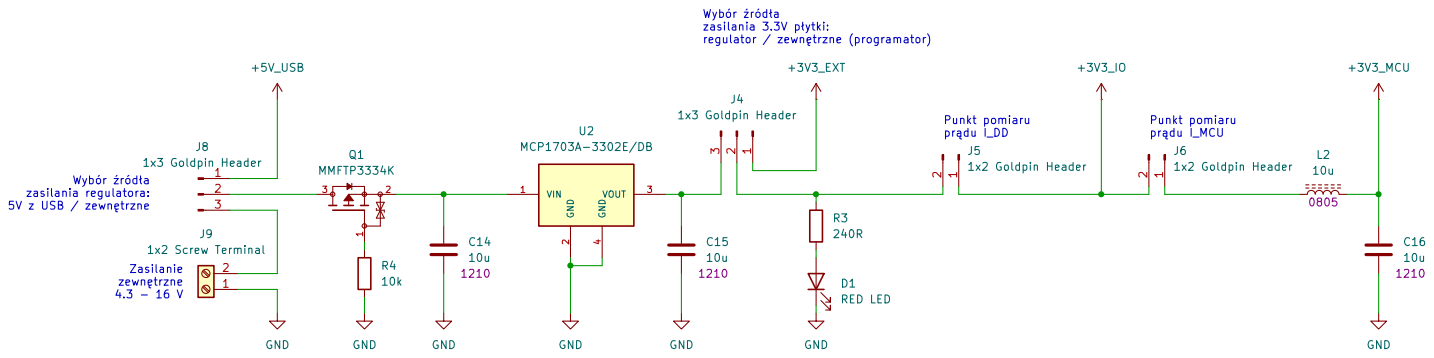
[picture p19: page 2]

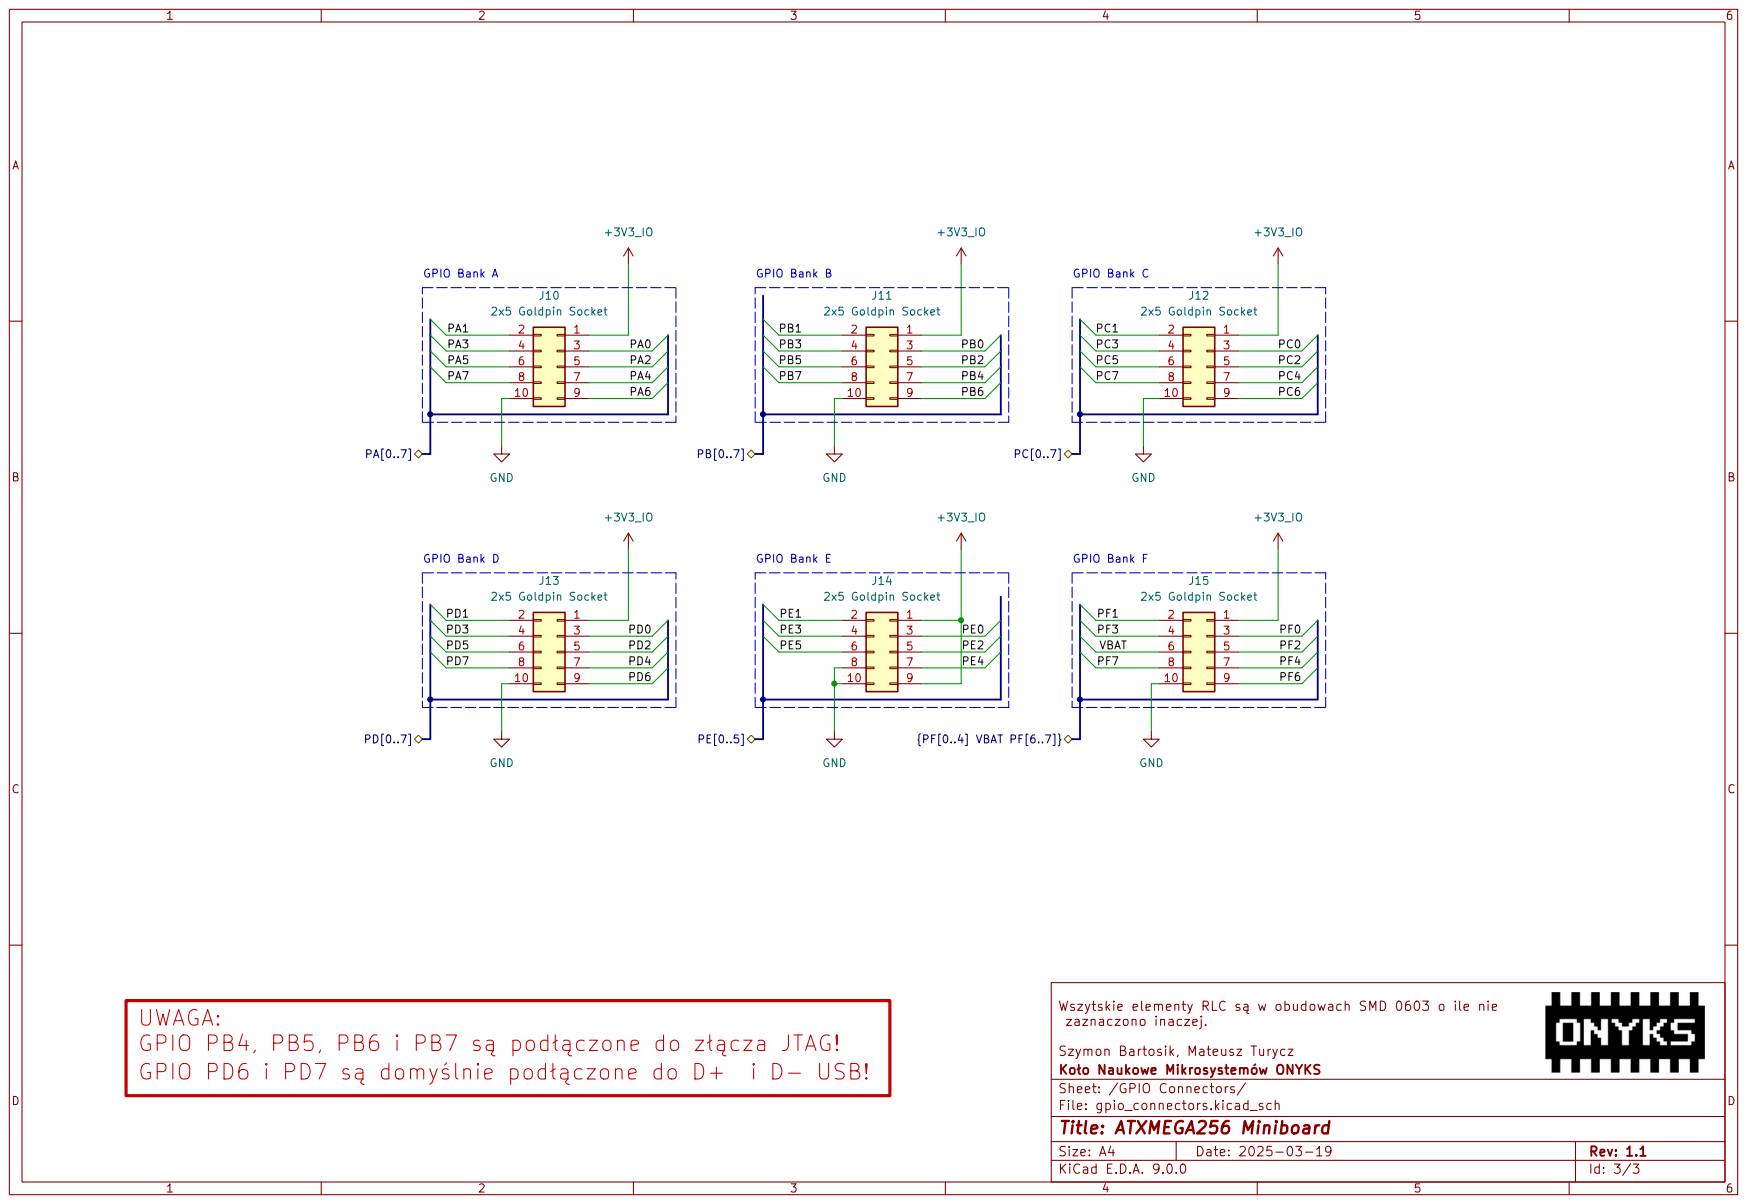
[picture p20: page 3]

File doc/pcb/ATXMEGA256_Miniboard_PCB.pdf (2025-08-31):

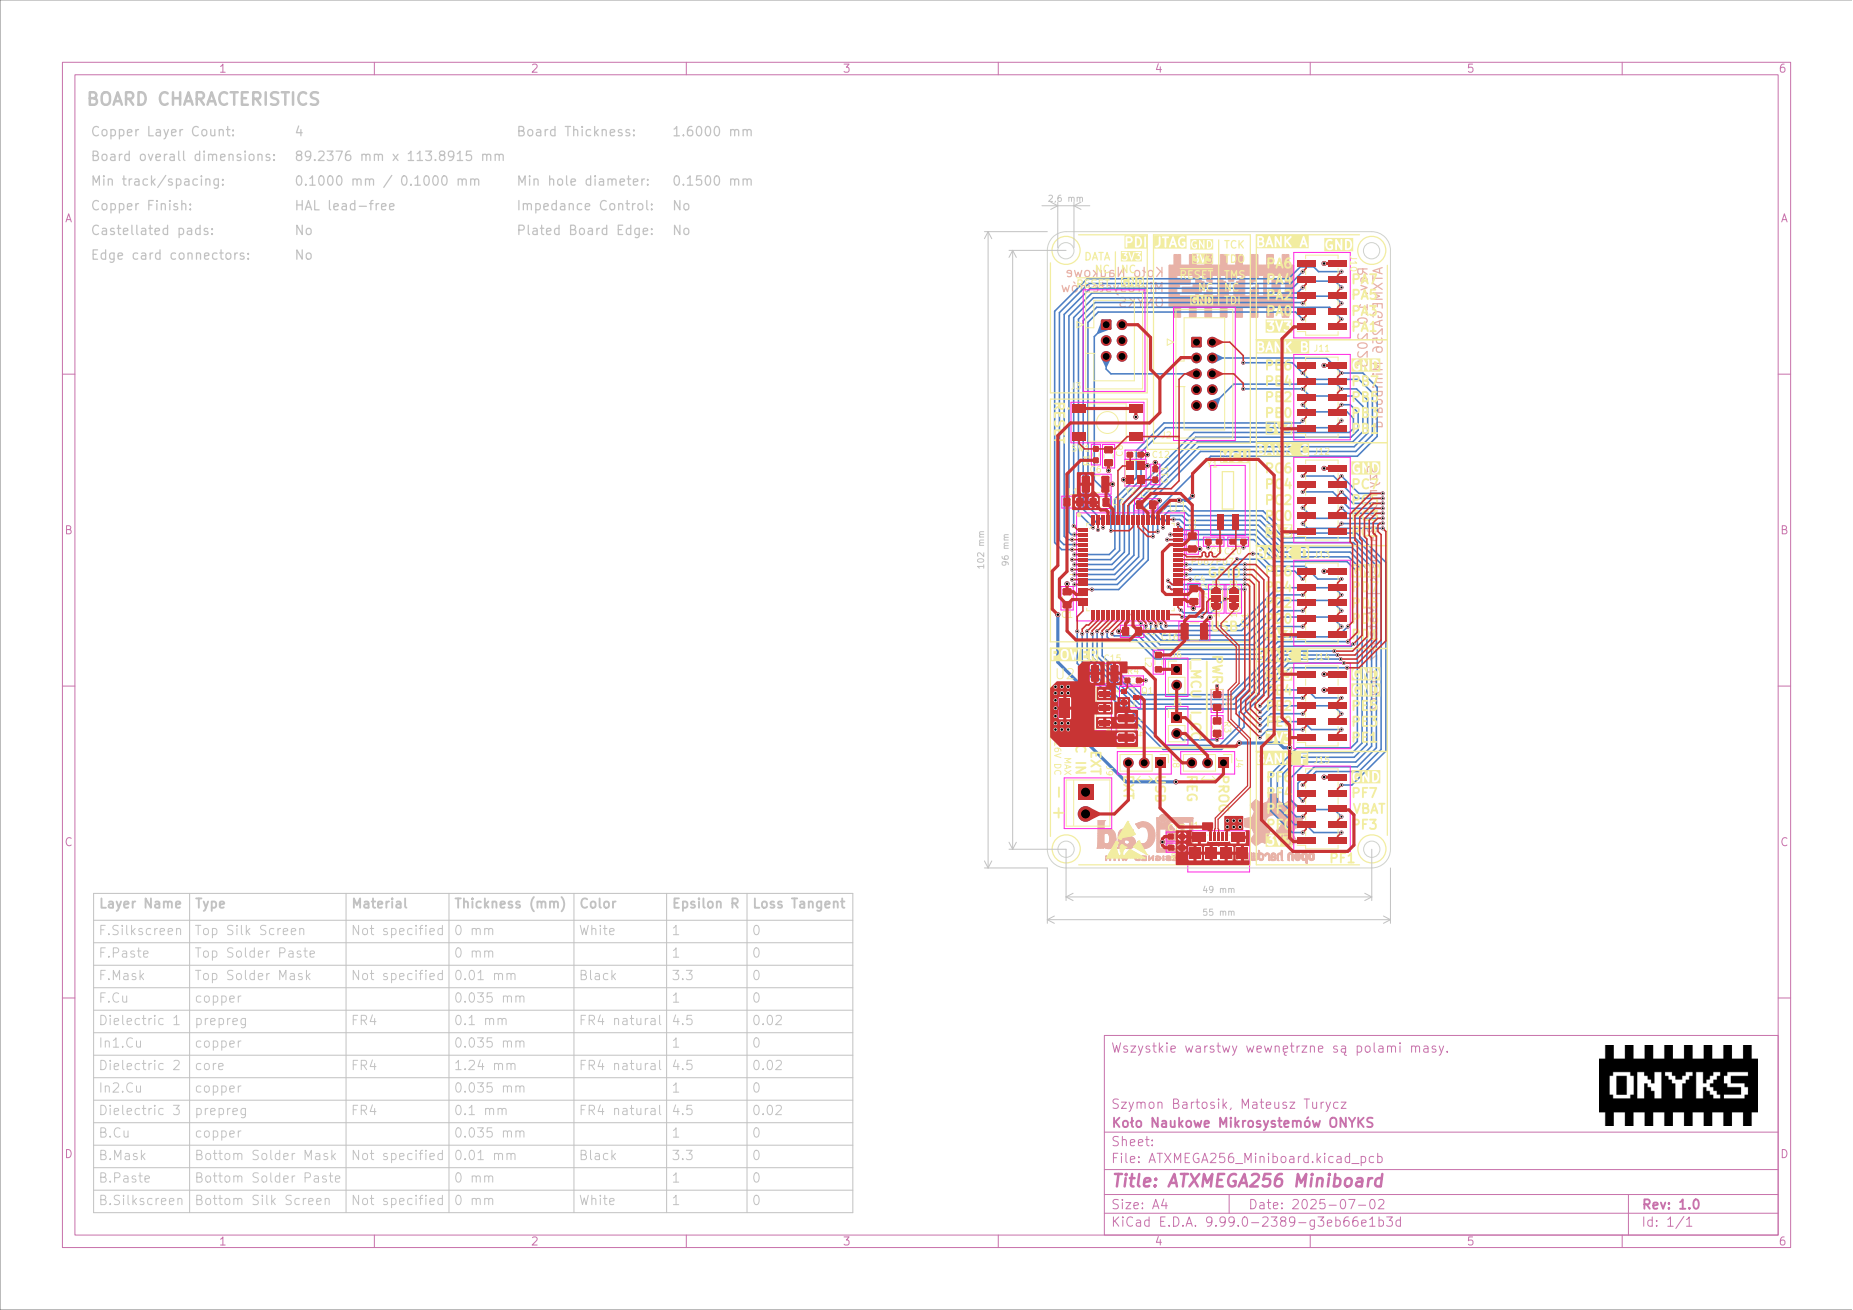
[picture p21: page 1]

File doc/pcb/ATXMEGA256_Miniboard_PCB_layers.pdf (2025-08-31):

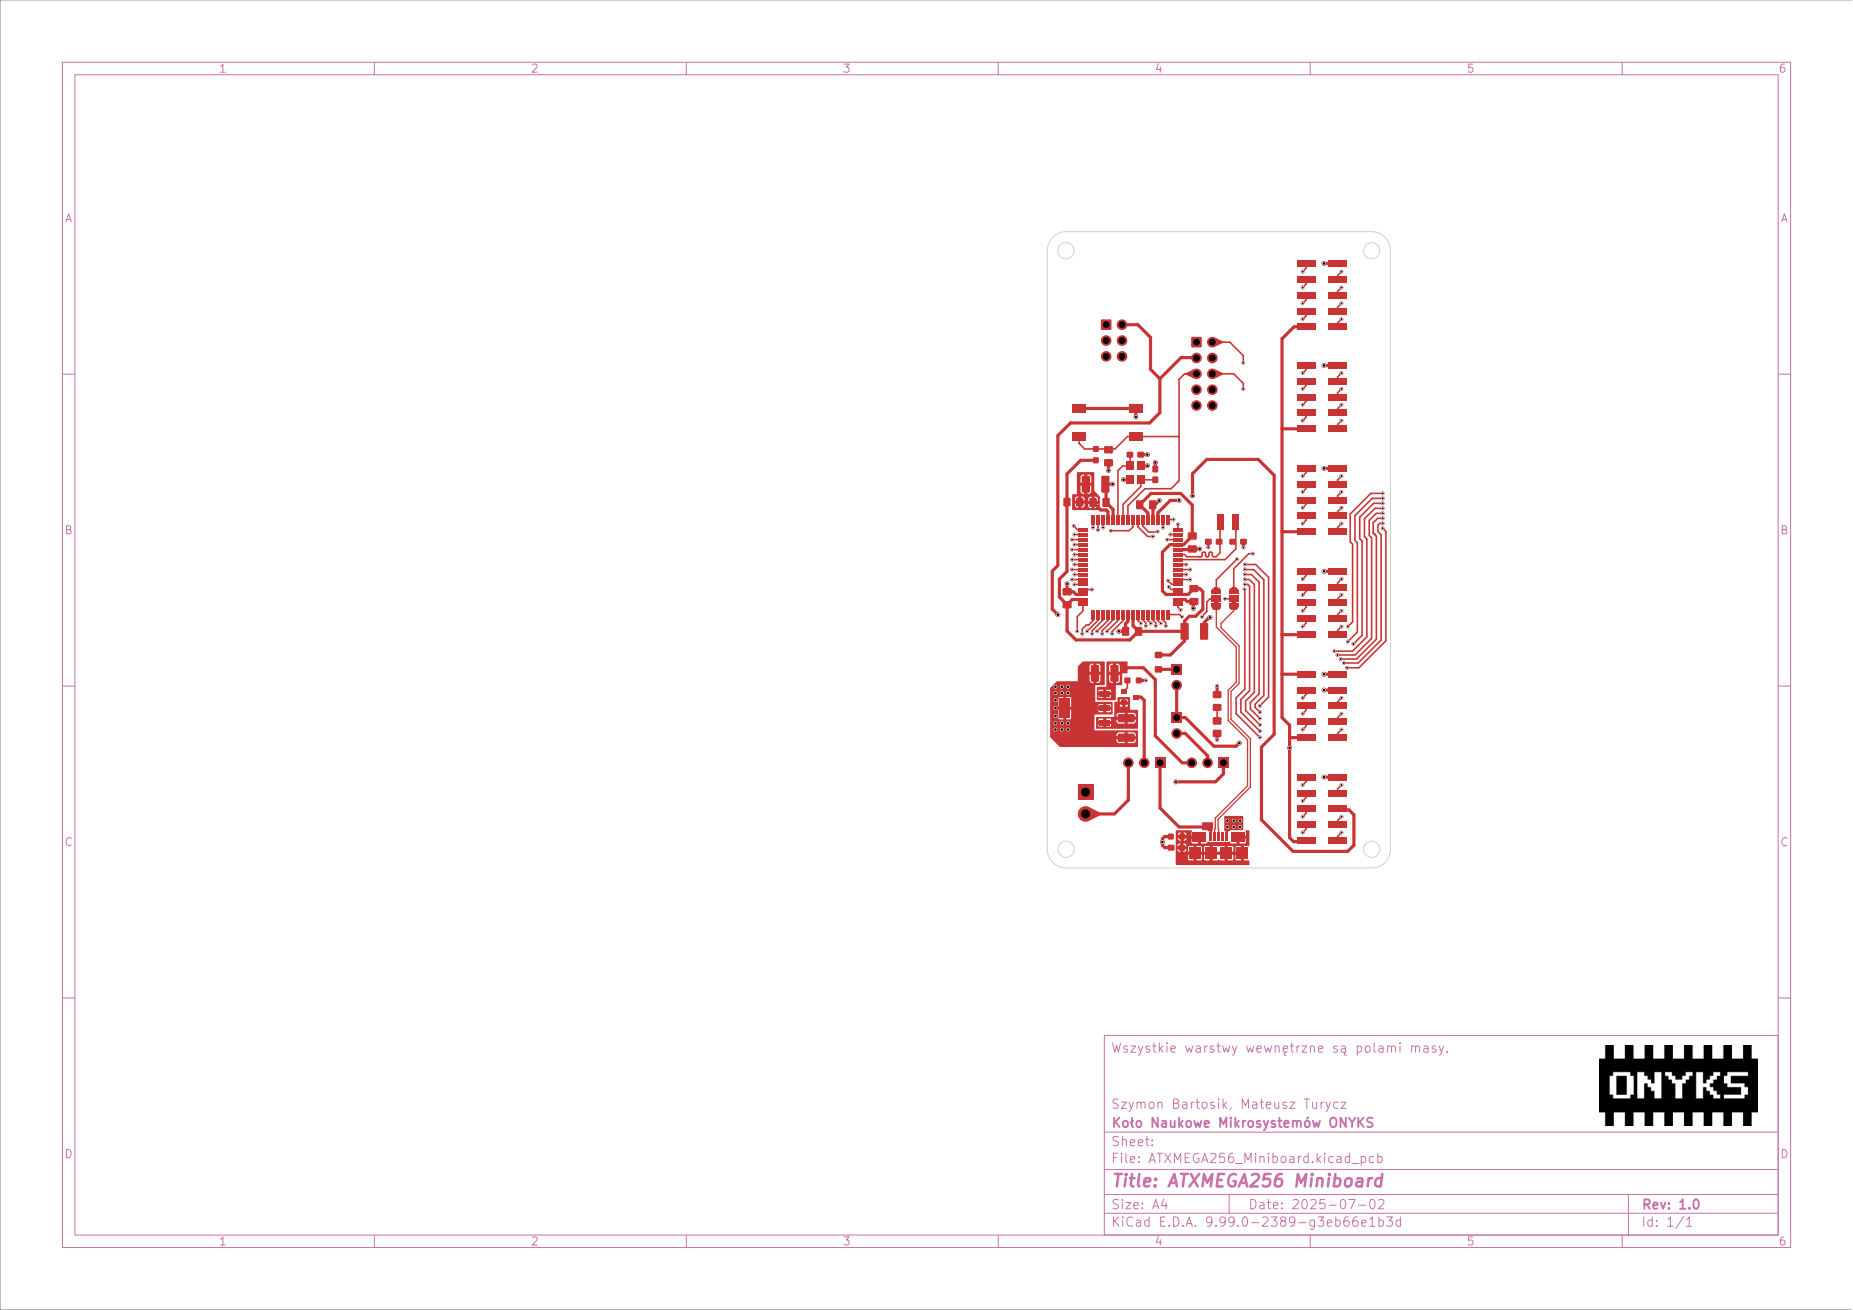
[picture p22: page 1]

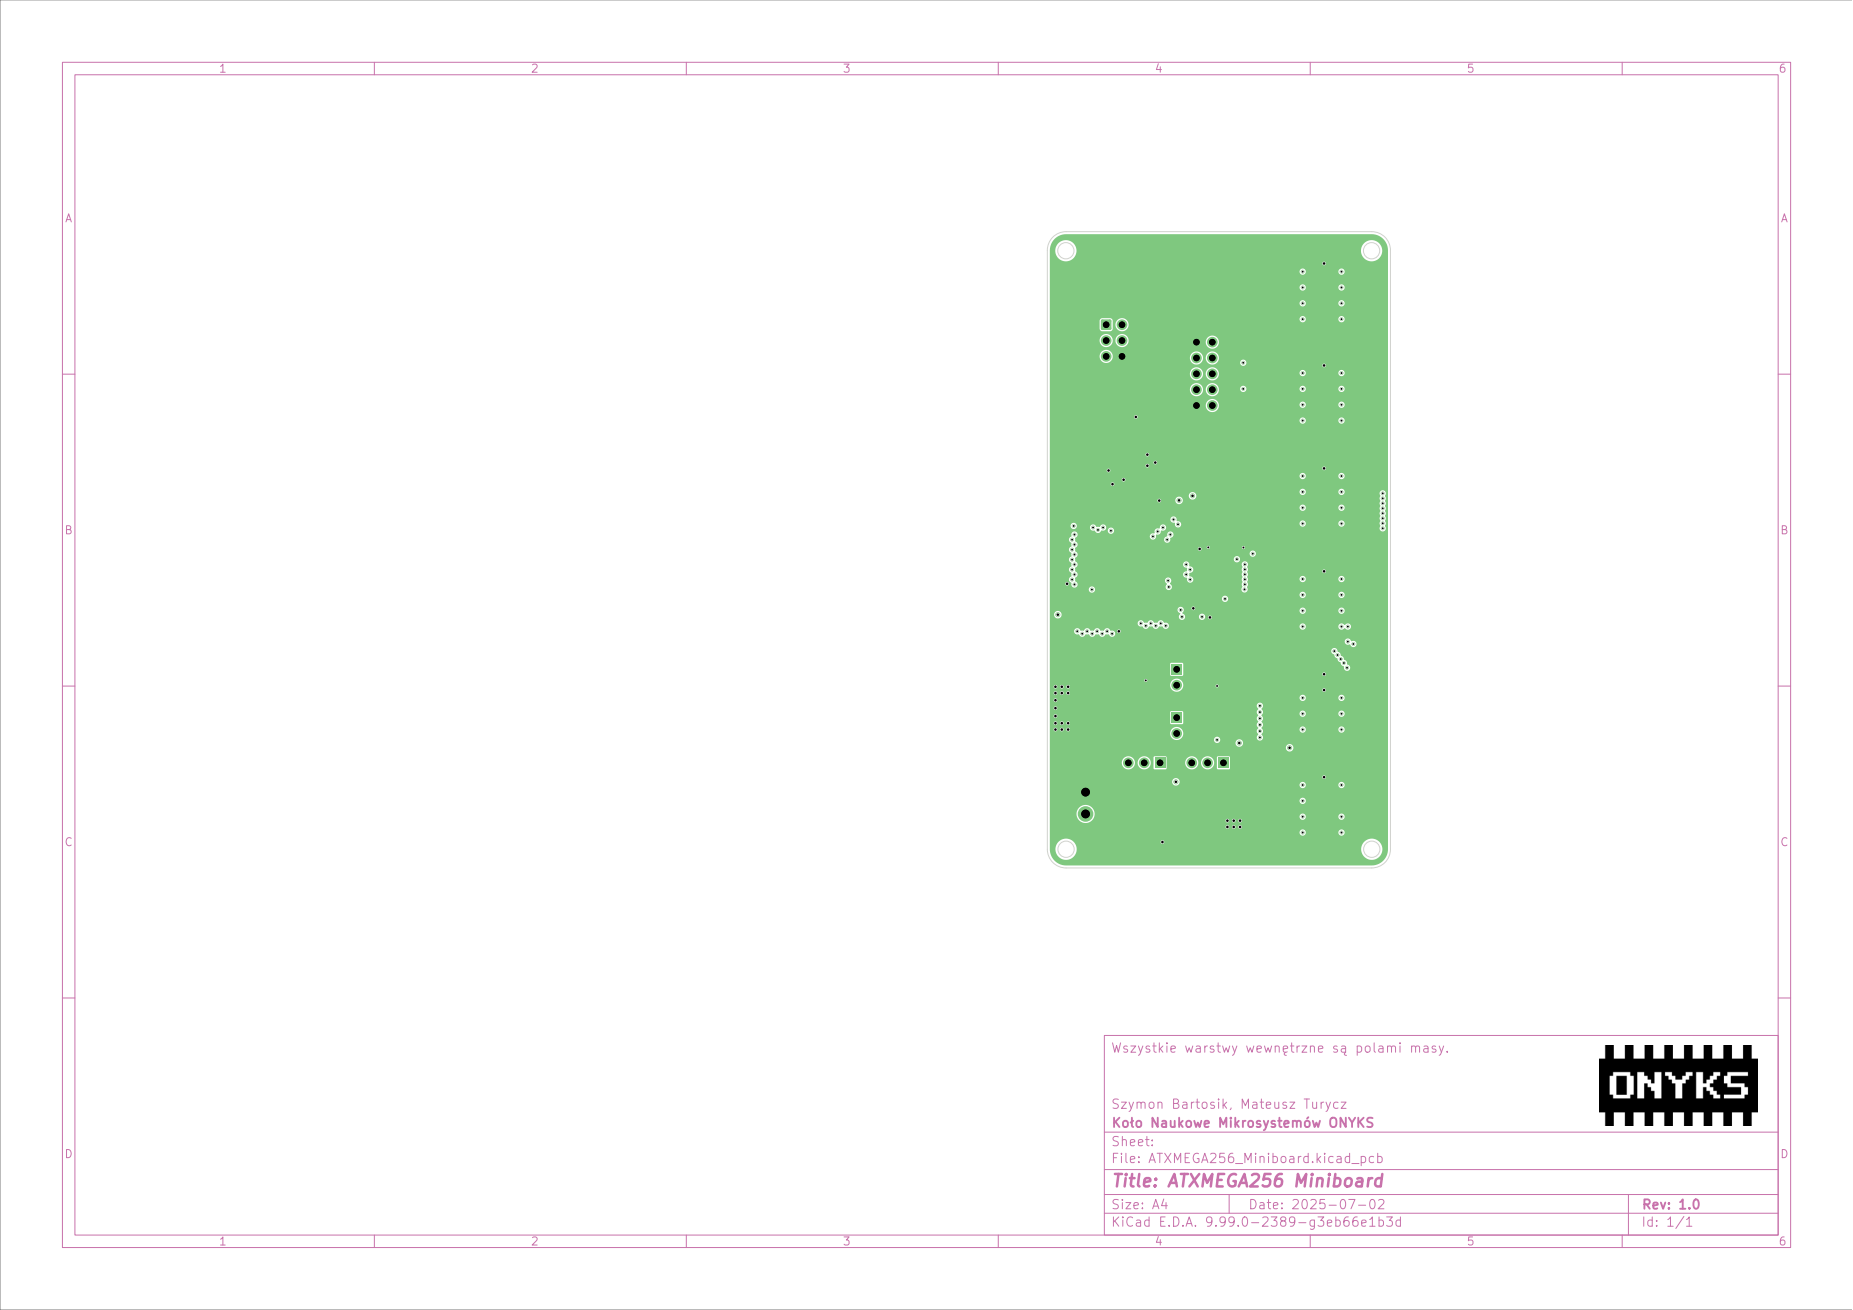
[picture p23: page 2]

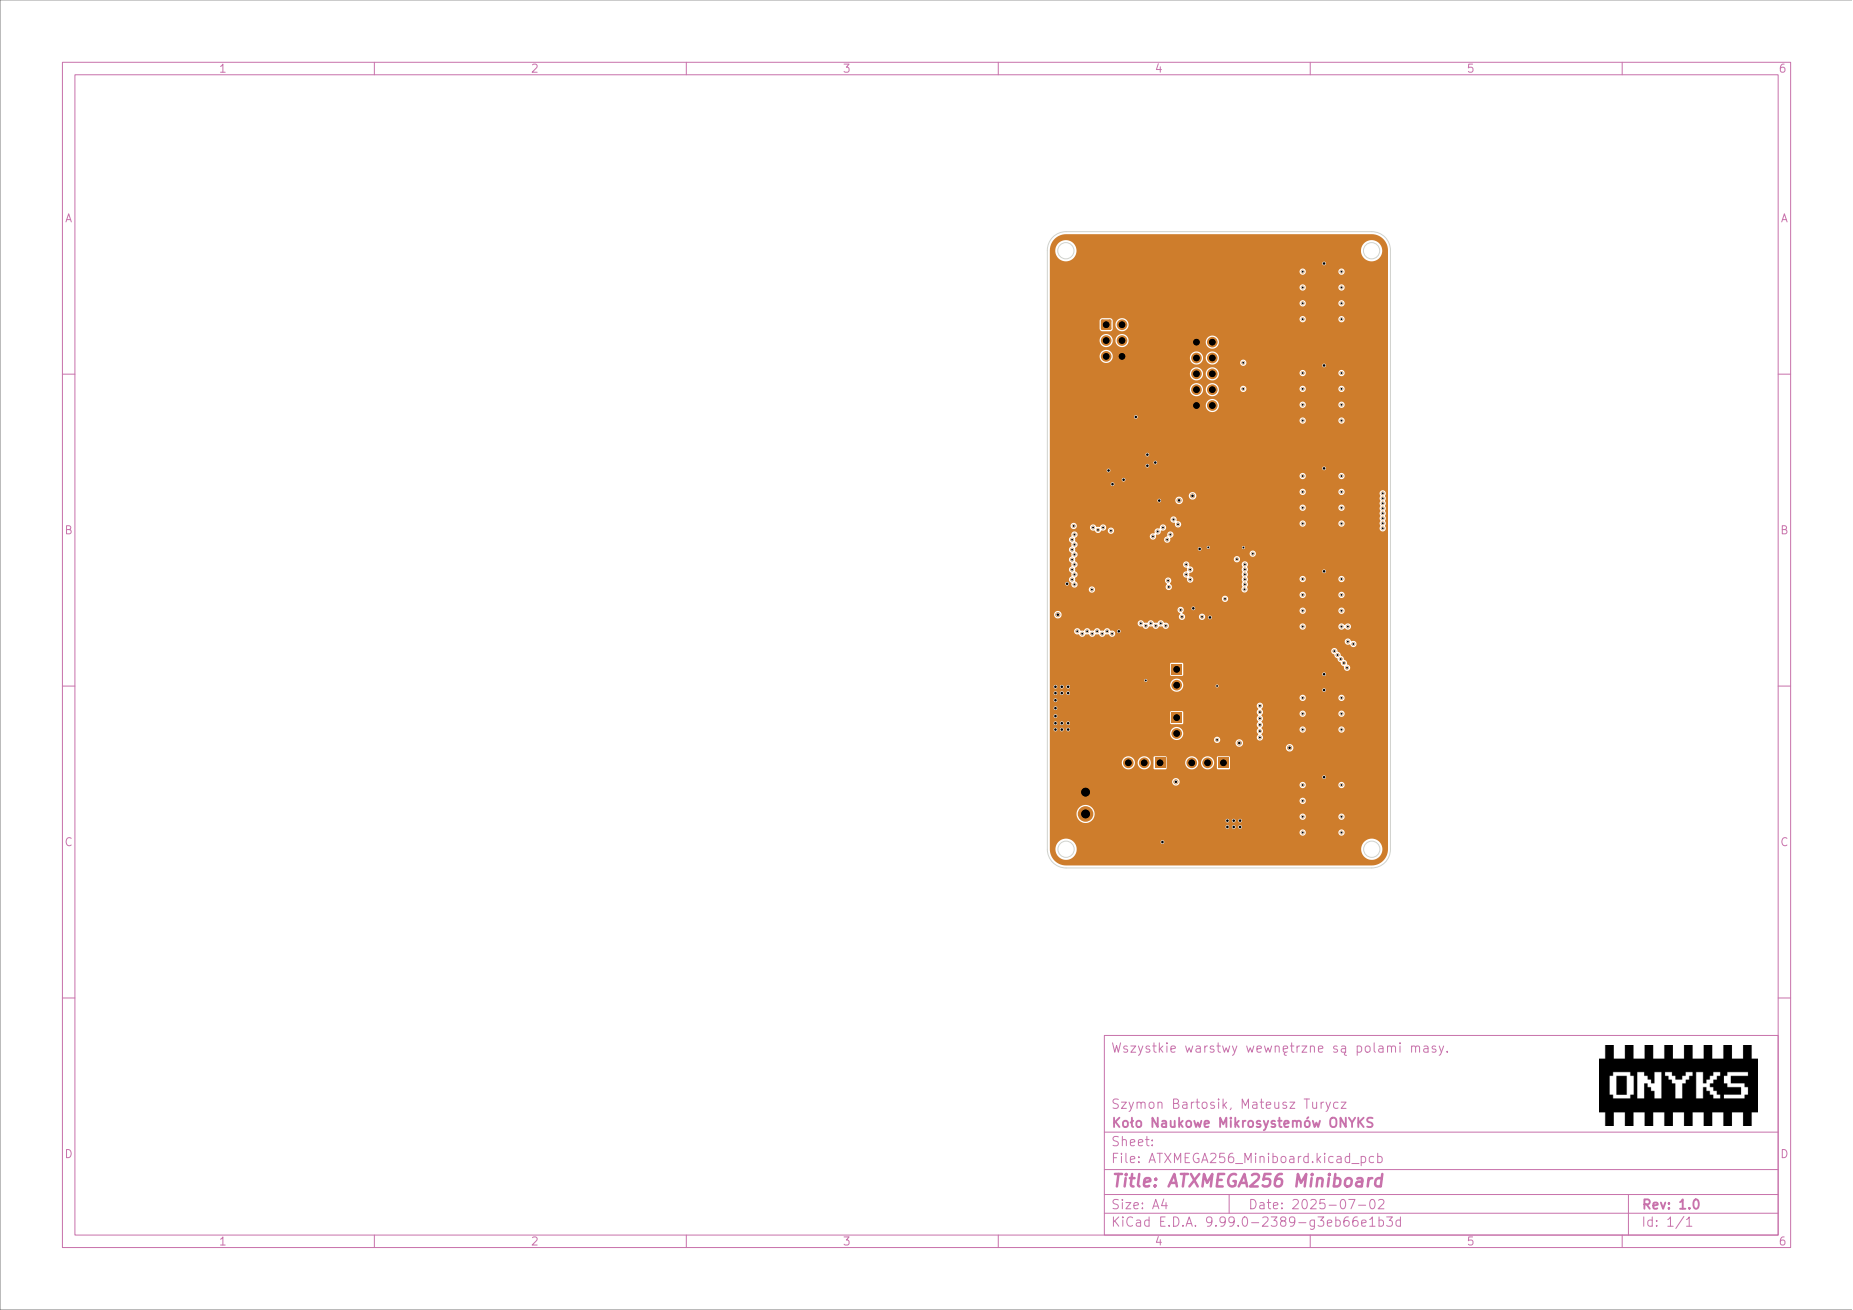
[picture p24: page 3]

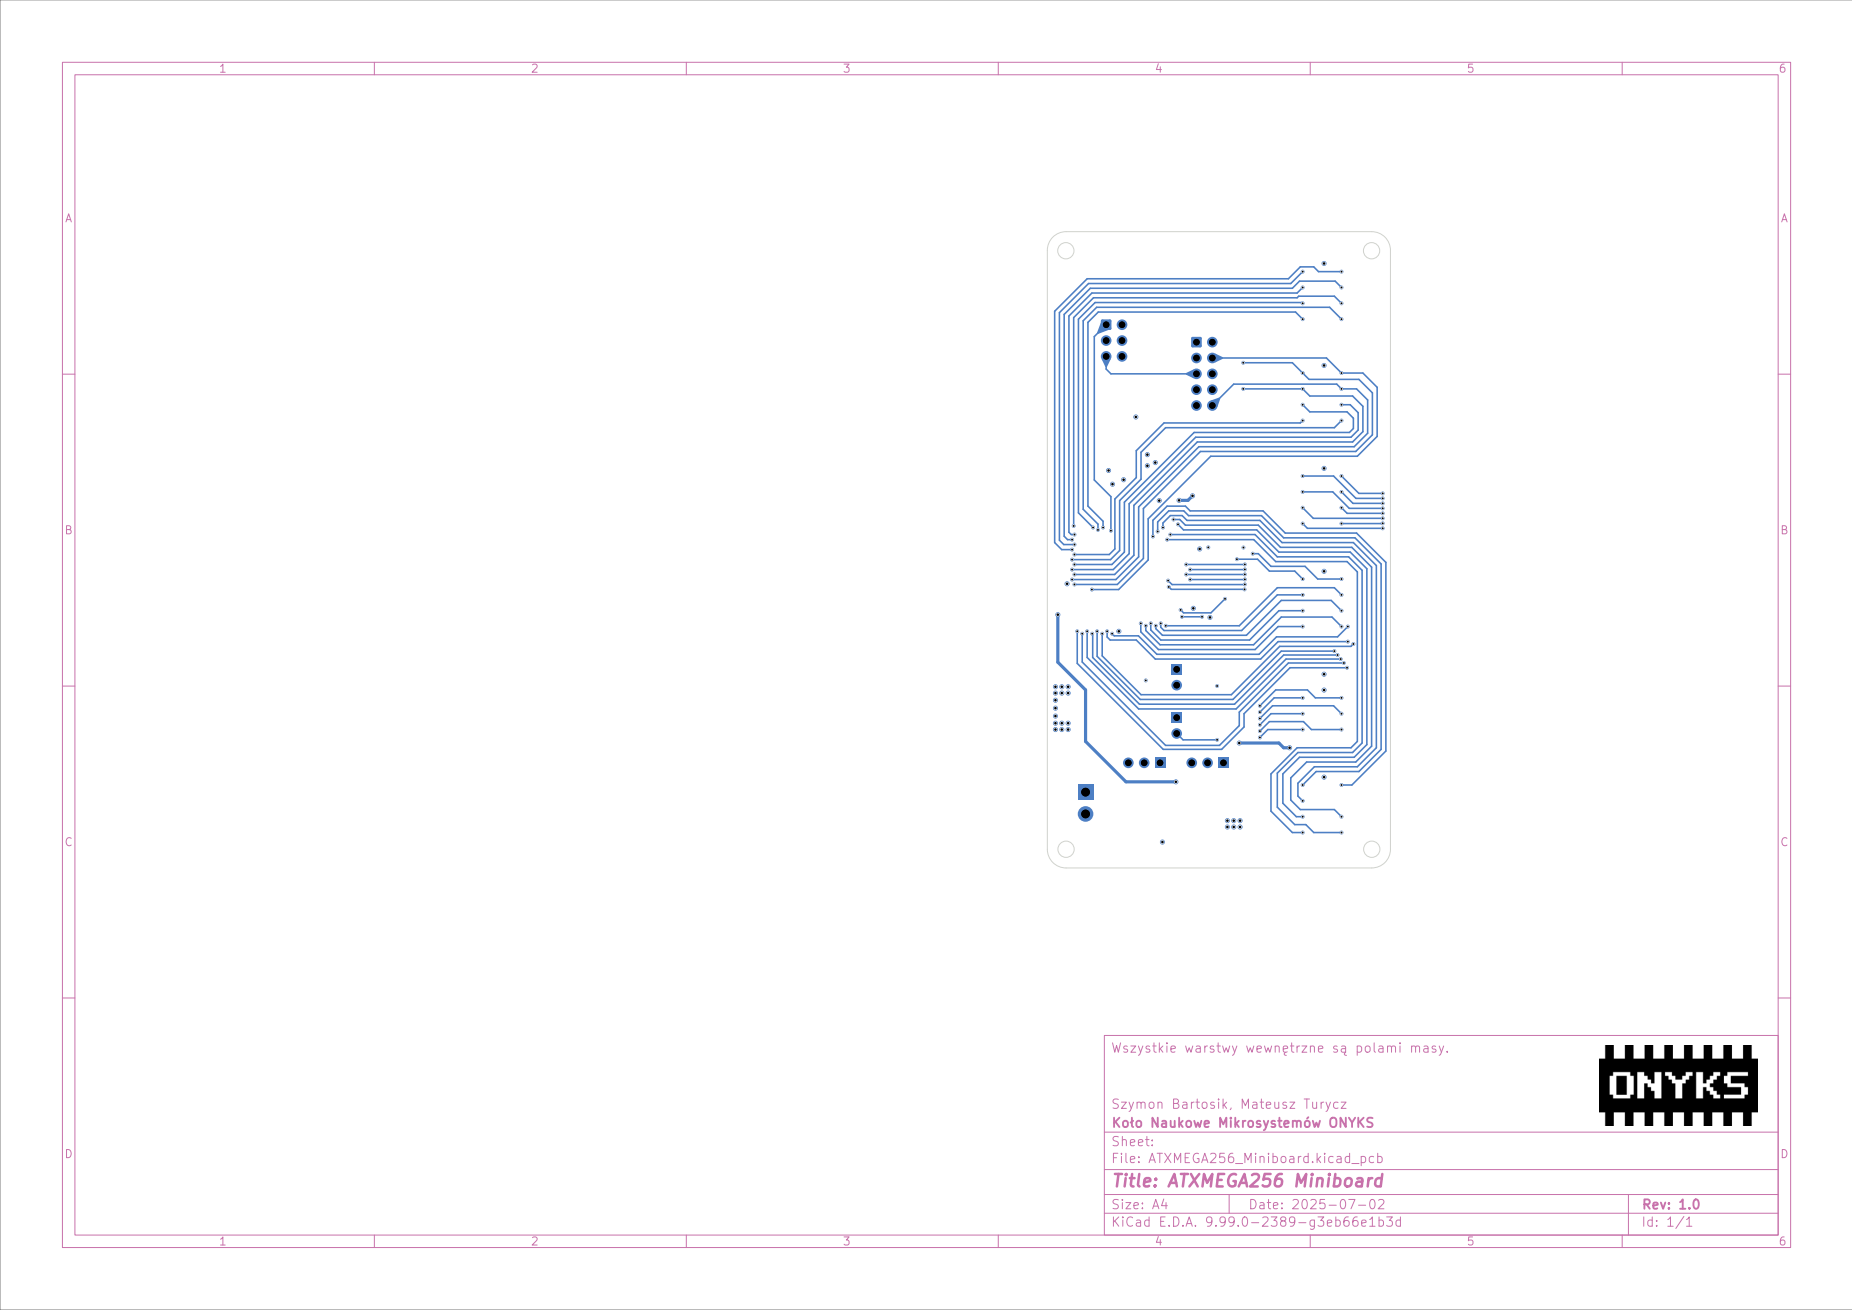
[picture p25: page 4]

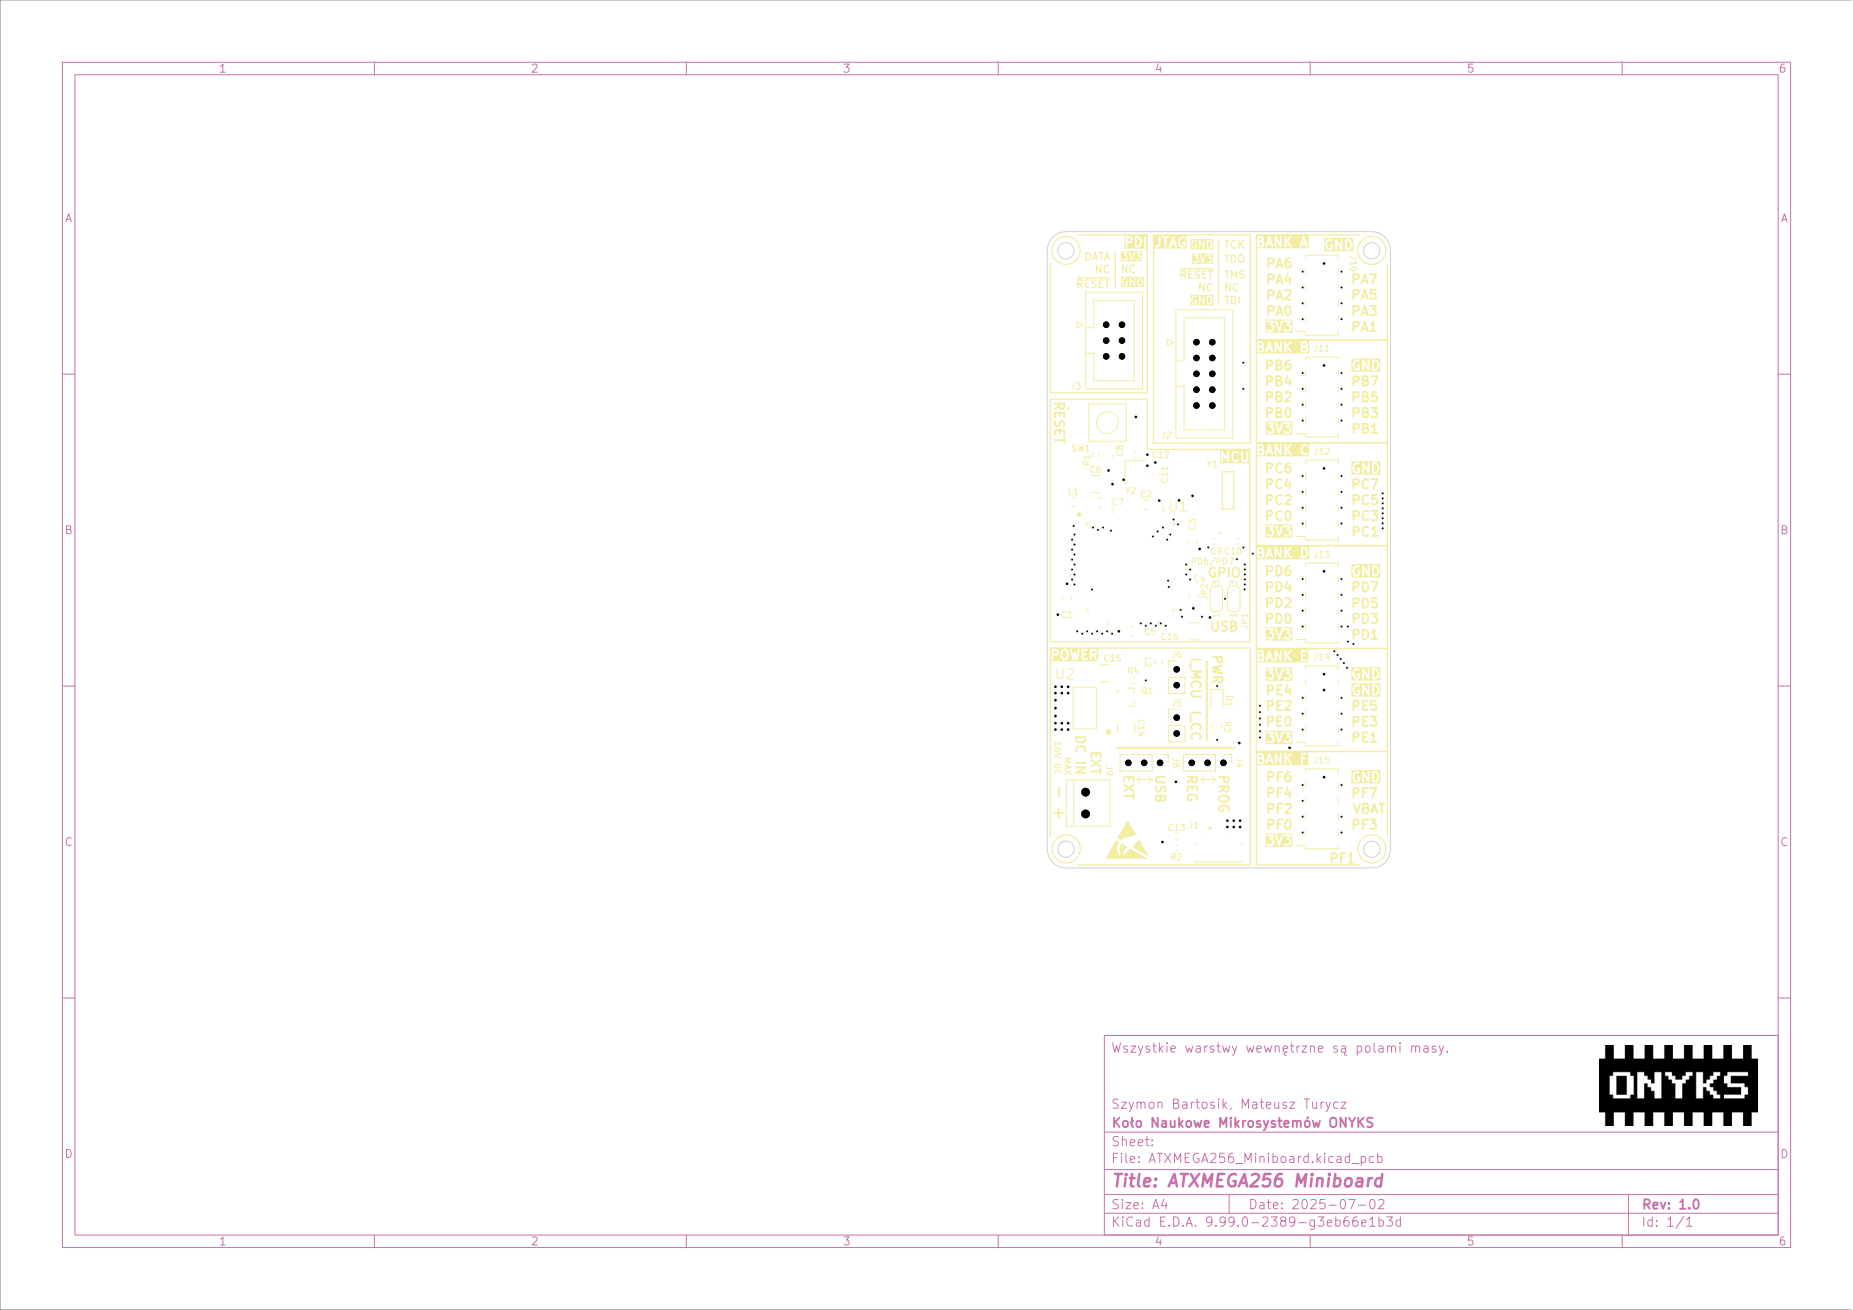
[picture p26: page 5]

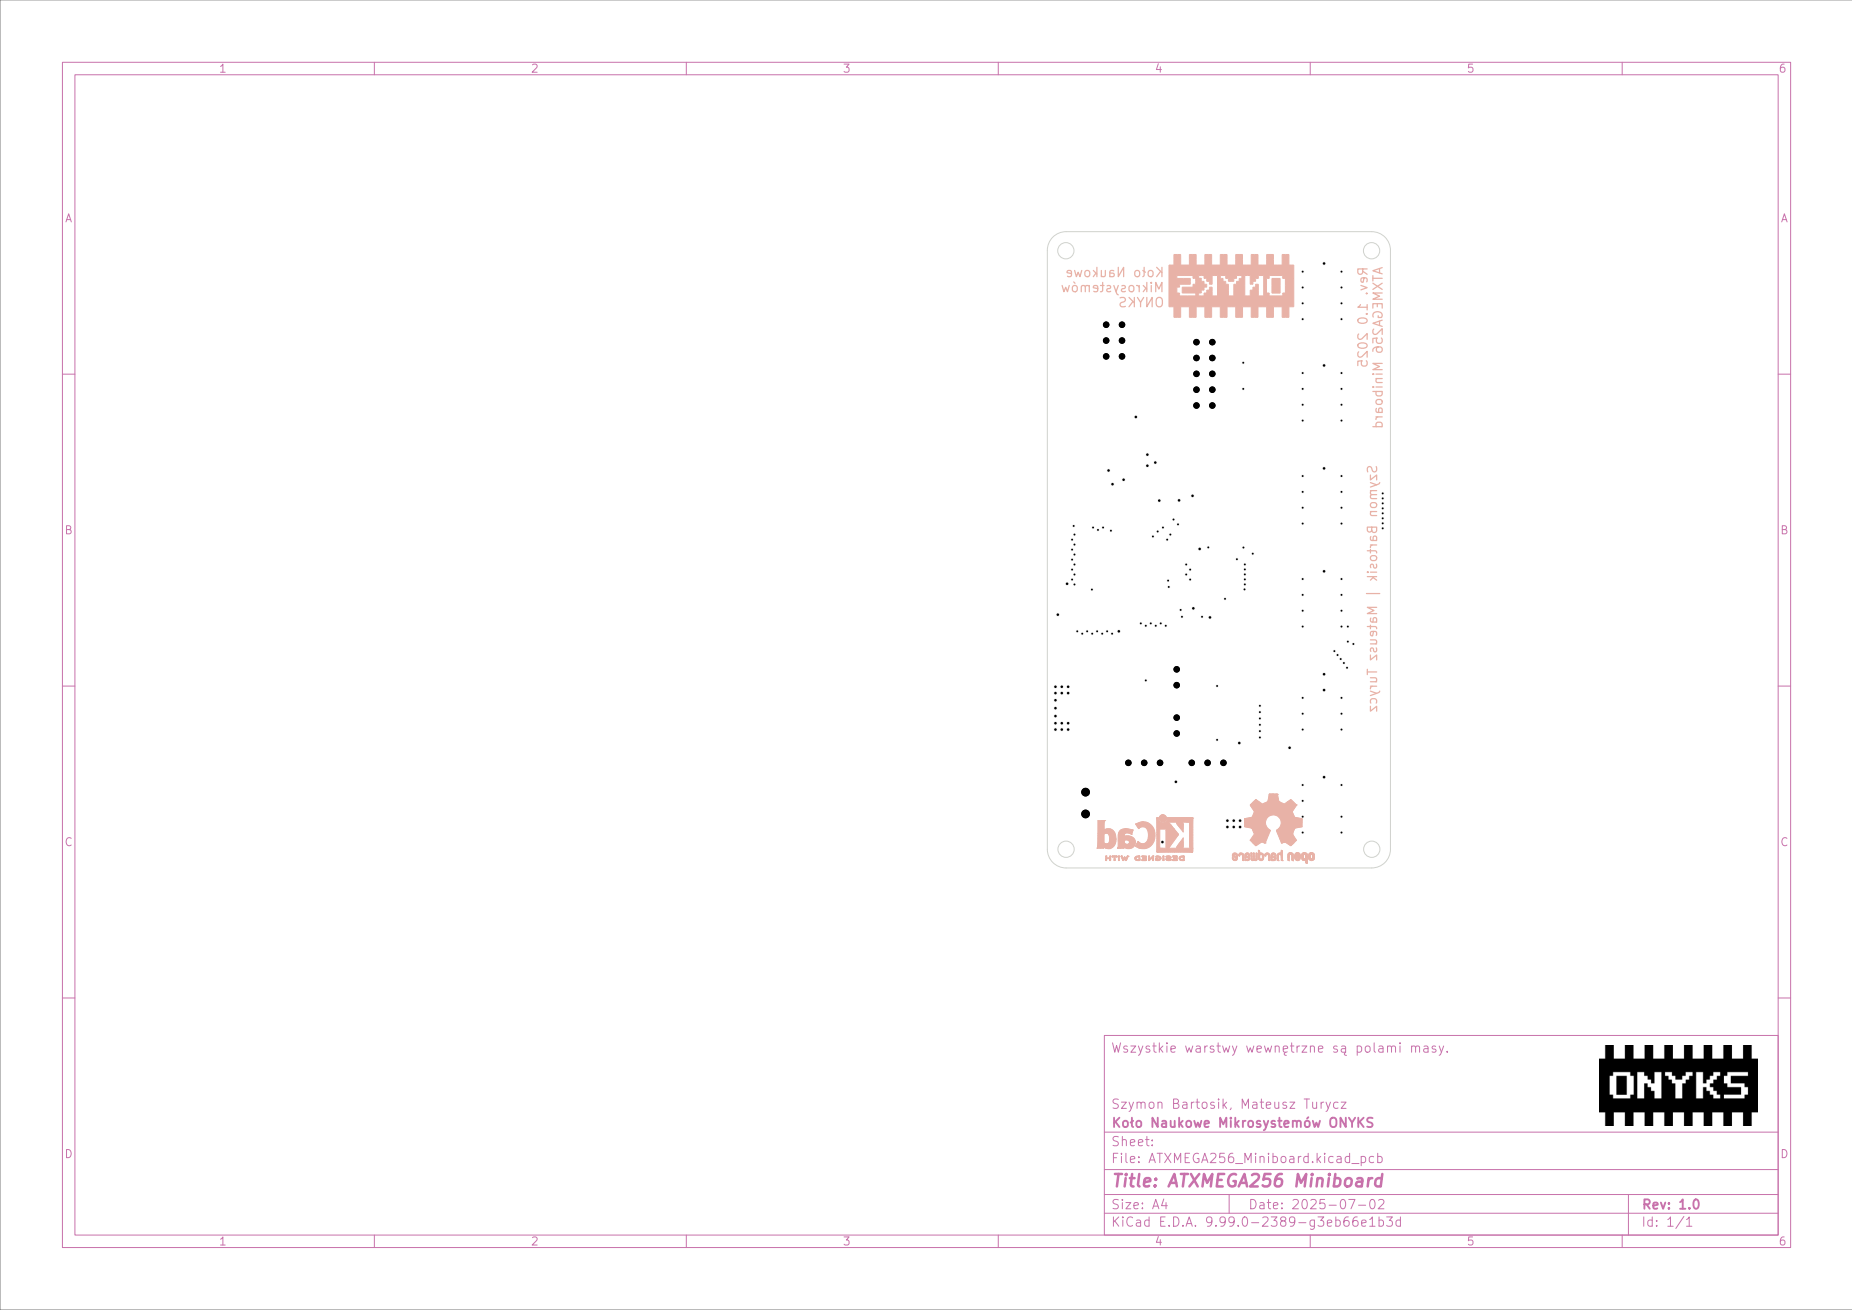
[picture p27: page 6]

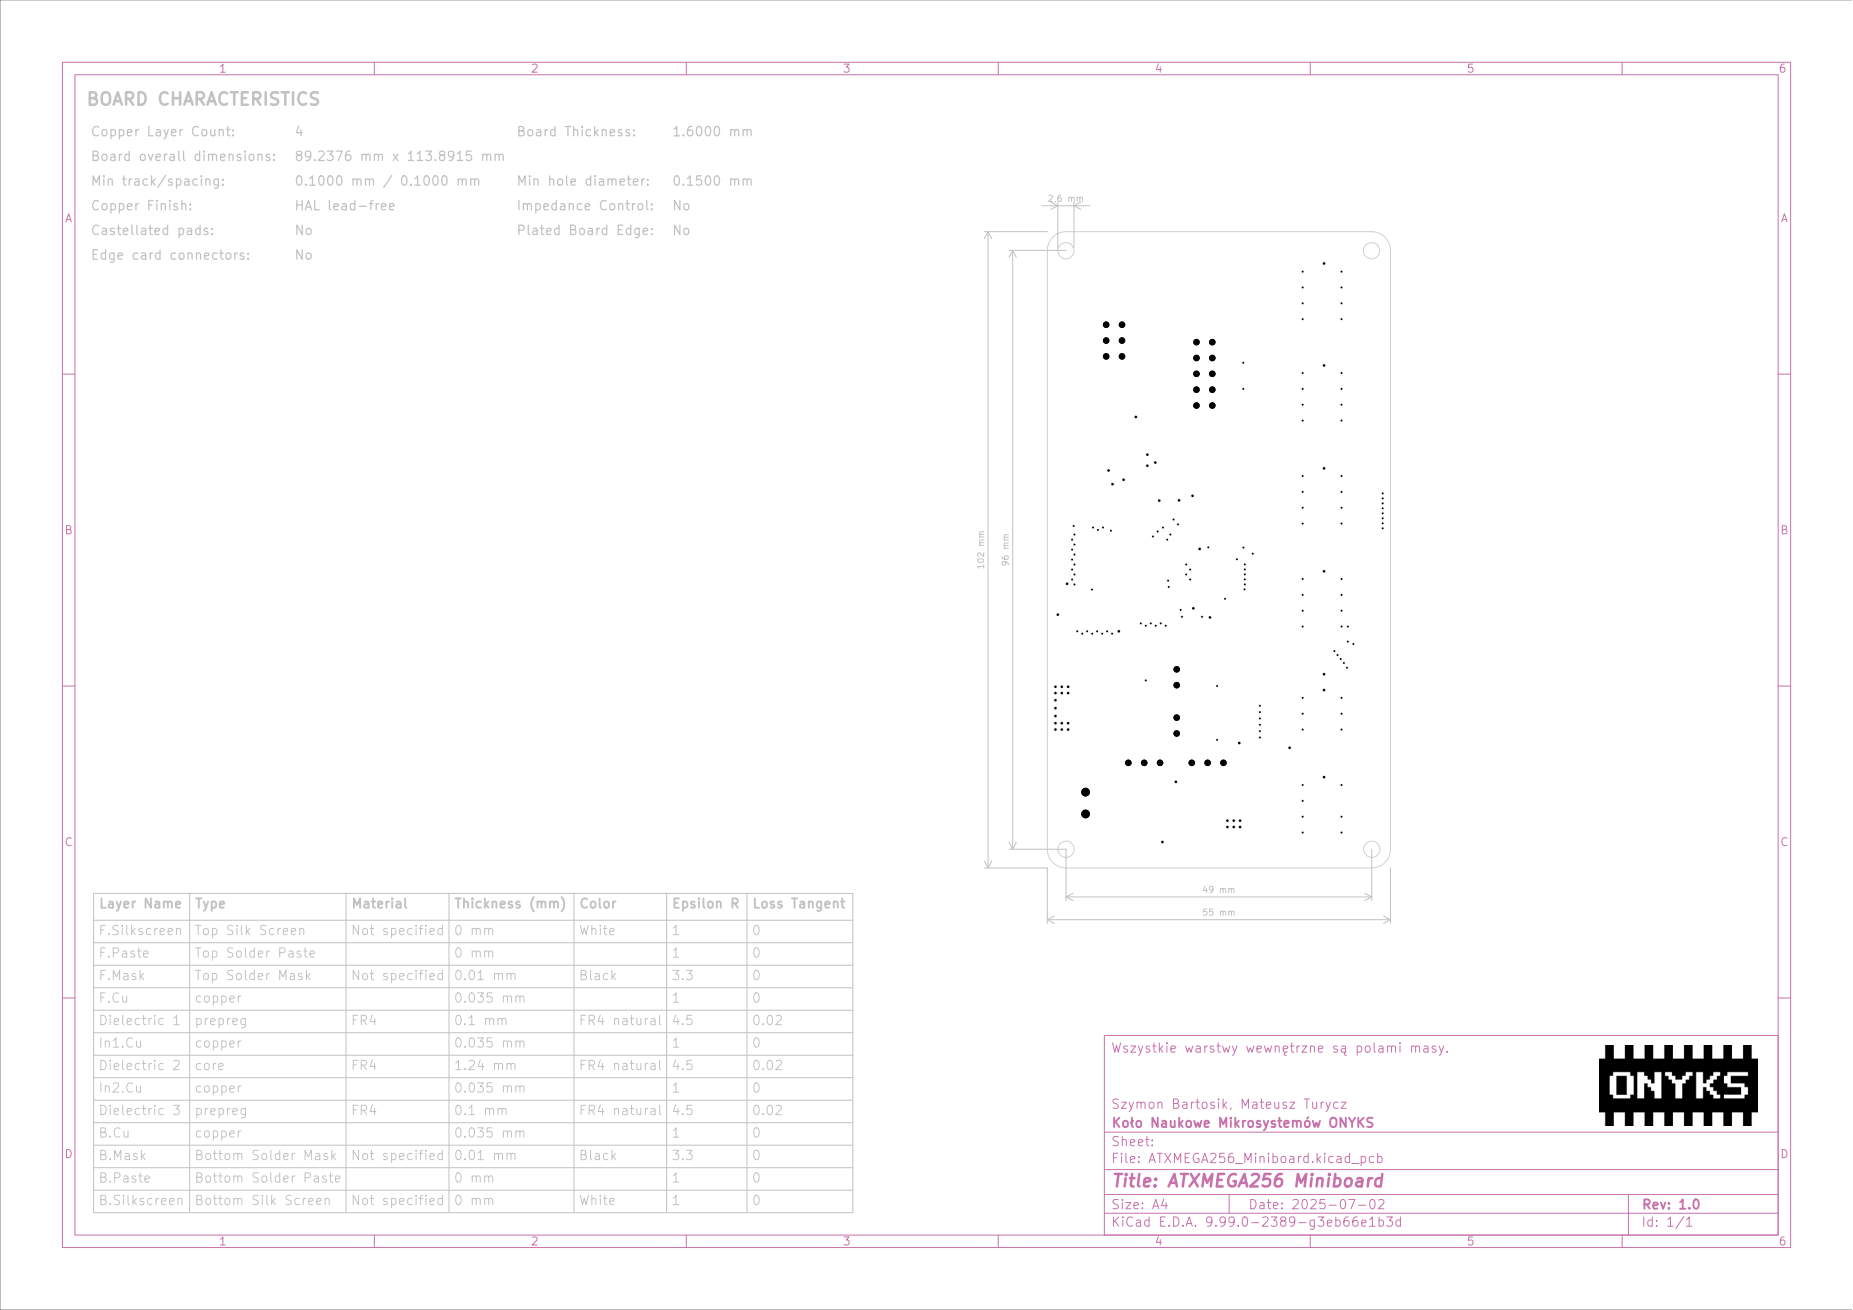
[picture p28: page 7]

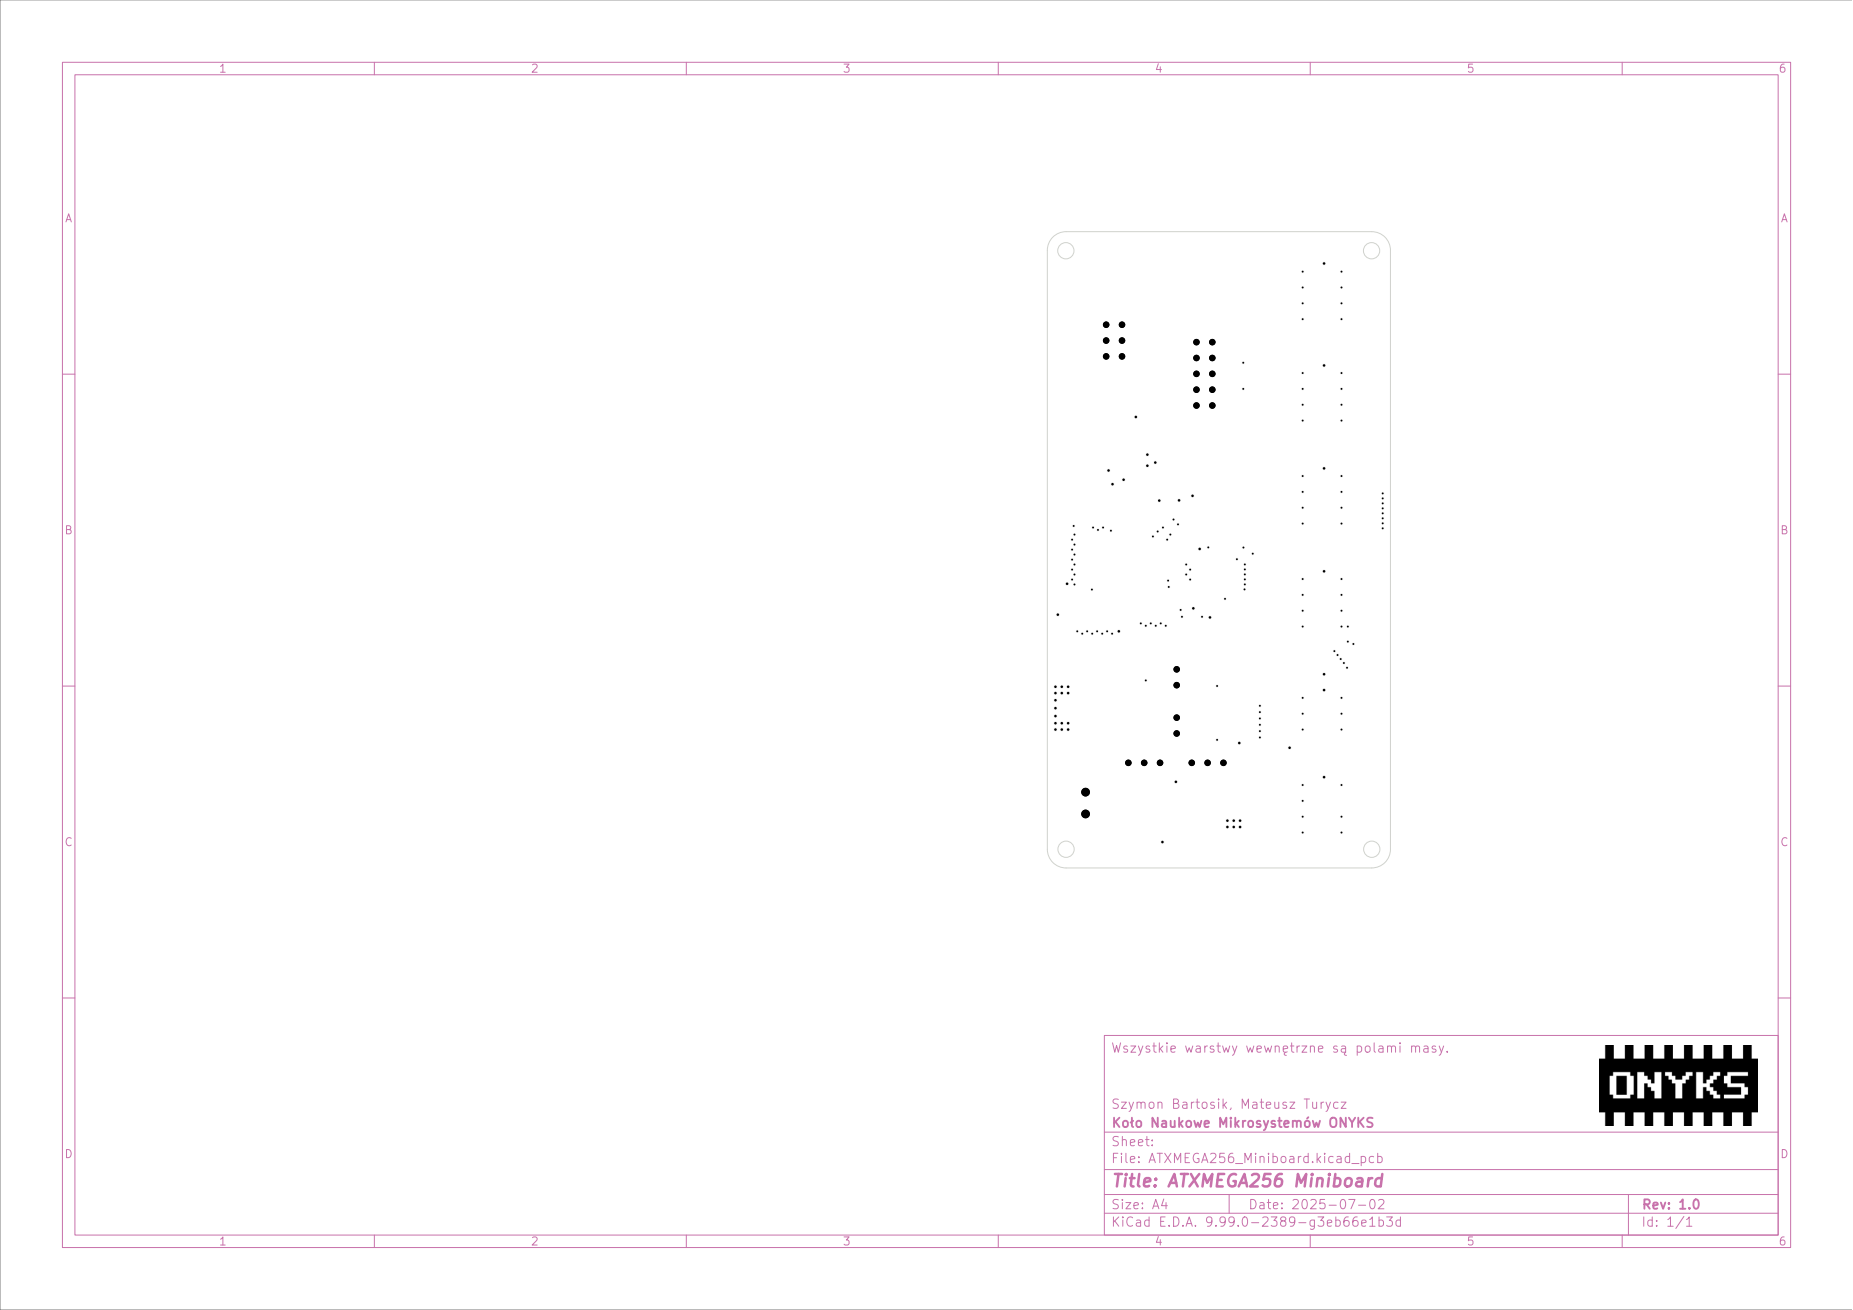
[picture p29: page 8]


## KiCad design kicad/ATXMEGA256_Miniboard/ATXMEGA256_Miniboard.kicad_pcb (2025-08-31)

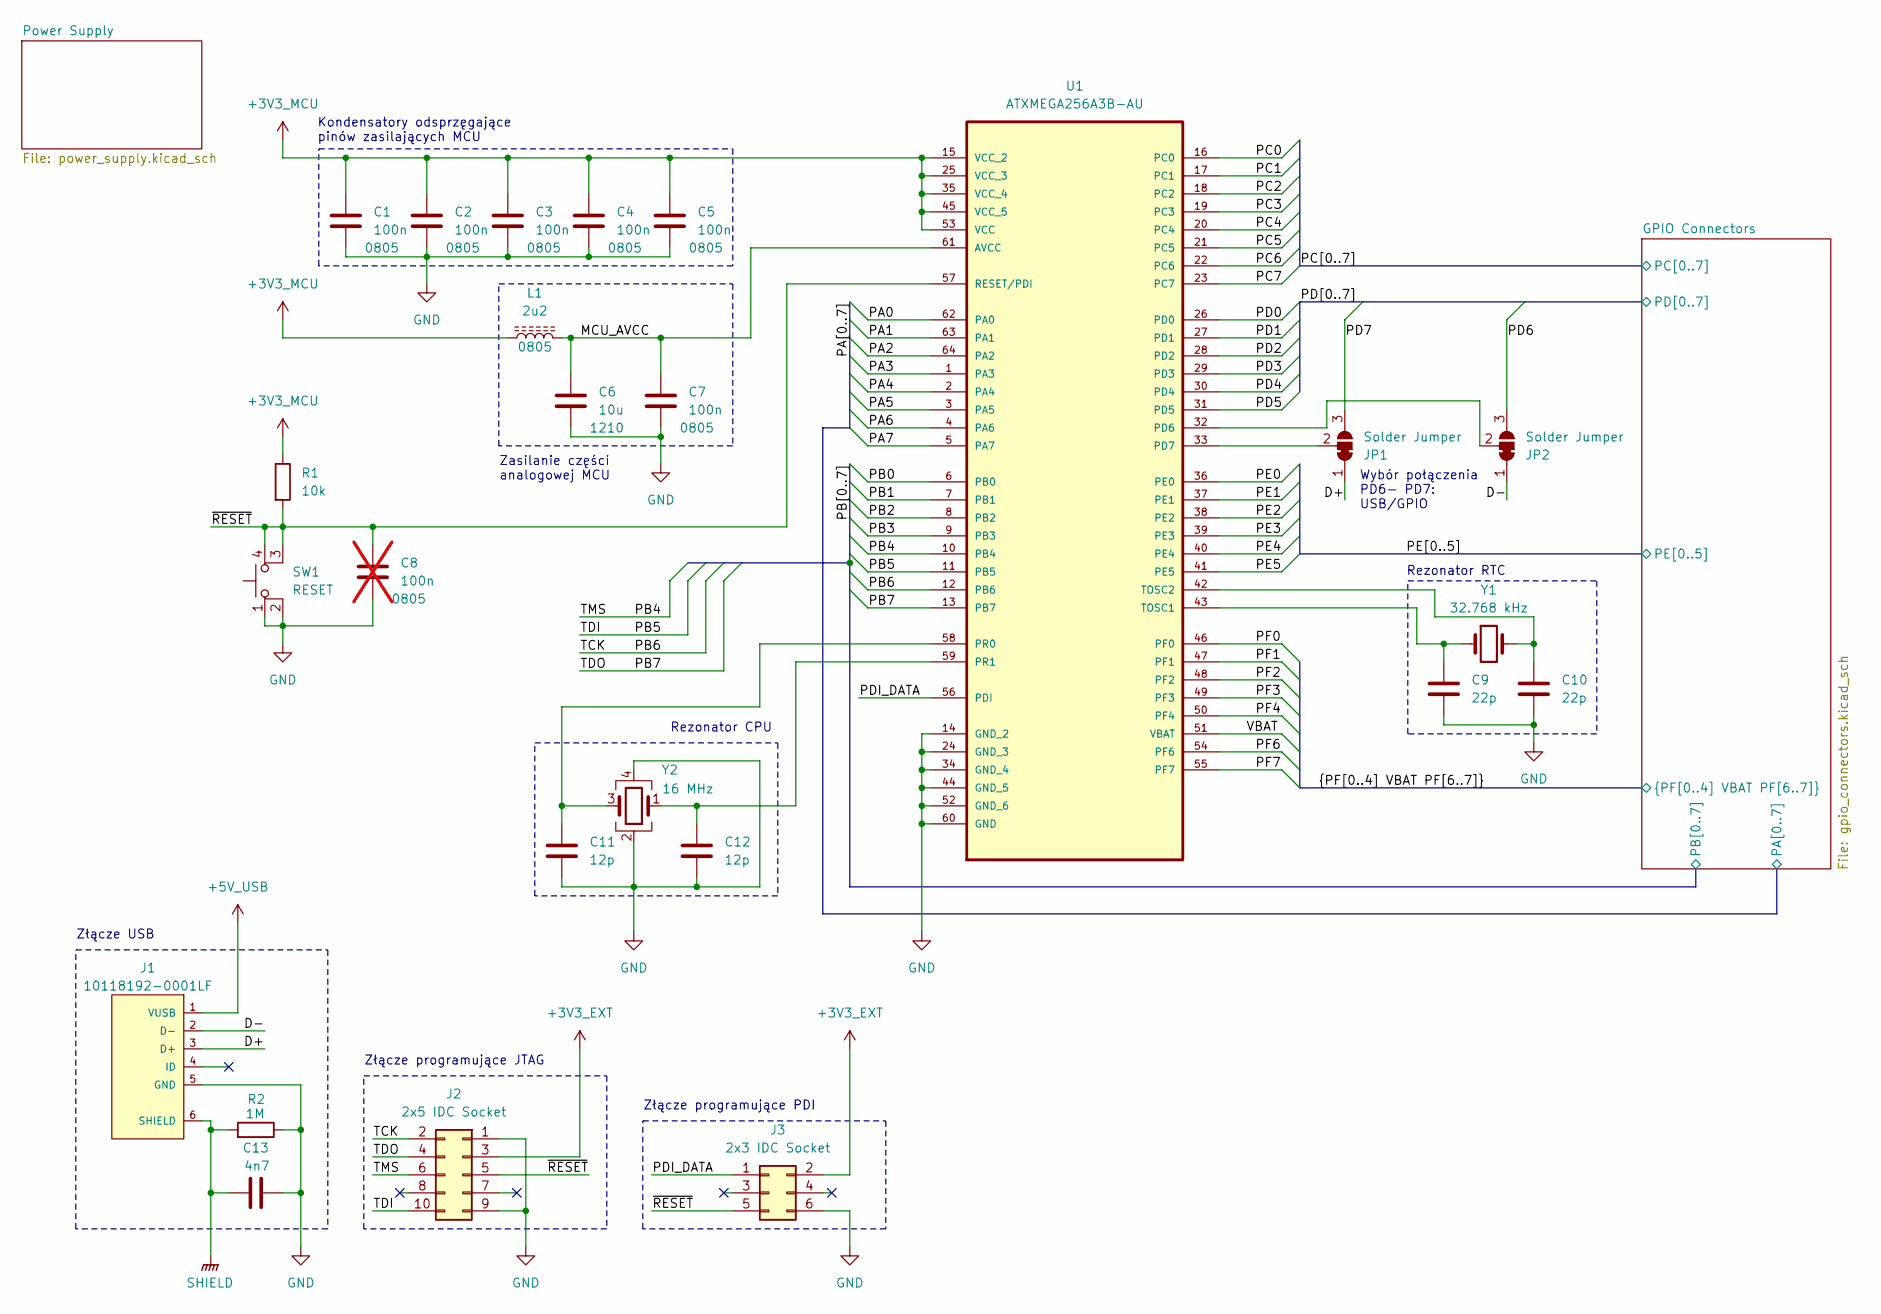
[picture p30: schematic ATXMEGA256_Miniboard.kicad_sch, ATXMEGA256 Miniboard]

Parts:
C1, C2, C3, C4, C5, C7: 100n; C_0805_2012Metric_Pad1.18x1.45mm_HandSolder; Part Number C0805C104J4RACTU
C6: 10u; C_1210_3225Metric_Pad1.33x2.70mm_HandSolder; Part Number C1210C106K4RAC
C8: 100n; C_0805_2012Metric_Pad1.18x1.45mm_HandSolder; Part Number C0805C104J4RACTU; not fitted
C9, C10: 22p; C_0603_1608Metric_Pad1.08x0.95mm_HandSolder; Part Number C0603C220J5GAC7867
C11, C12: 12p; C_0603_1608Metric_Pad1.08x0.95mm_HandSolder; Part Number C0603C120J5GACTU
C13: 4n7; C_0603_1608Metric_Pad1.08x0.95mm_HandSolder; Part Number C0603C472K3RACTU
J1: 10118192-0001LF; AMPHENOL_10118192-0001LF; Part Number 10118192-0001LF
J2: 2x5 IDC Socket; IDC-Header_2x05_P2.54mm_Vertical; Part Number DS1013-10SSIB1-B-0
J3: 2x3 IDC Socket; IDC-Header_2x03_P2.54mm_Vertical; Part Number T821106A1S100CEU
JP1, JP2: Solder Jumper; SolderJumper-3_P1.3mm_Bridged12_RoundedPad1.0x1.5mm_NumberL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
L1: 2u2; L_0805_2012Metric_Pad1.15x1.40mm_HandSolder; Part Number MLZ2012A2R2WT000
R1: 10k; R_0603_1608Metric_Pad0.98x0.95mm_HandSolder; Part Number 0603SAJ0103T5E
R2: 1M; R_0603_1608Metric_Pad0.98x0.95mm_HandSolder; Part Number 0603SAJ0105T5E
SW1: RESET; SW_SMD_2-1437565-8_4_4.50_6.00_6.00_5.00; Part Number FSM2JSMAA
U1: ATXMEGA256A3B-AU; QFP80P1600X1600X120-64N; Part Number ATXMEGA256A3B-AU
Y1: 32.768 kHz; LFXTAL025159Reel; Part Number LFXTAL025159
Y2: 16 MHz; Crystal_SMD_3225-4Pin_3.2x2.5mm; Part Number LFXTAL053426

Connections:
+3V3_EXT: J2.3, J3.2; also elsewhere on the board
+3V3_MCU: C1.2, C2.2, C3.2, C4.2, C5.2, L1.1, R1.1, U1.15 (VCC_2), U1.25 (VCC_3), U1.35 (VCC_4), U1.45 (VCC_5), U1.53 (VCC); also elsewhere on the board
+5V_USB: J1.1 (VUSB); also elsewhere on the board
/D+: J1.3 (D+), JP1.1 (A)
/D-: J1.2 (D-), JP2.1 (A)
/MCU_AVCC: C6.2, C7.2, L1.2, U1.61 (AVCC)
/PA0: U1.62 (PA0); also elsewhere on the board
/PA1: U1.63 (PA1); also elsewhere on the board
/PA2: U1.64 (PA2); also elsewhere on the board
/PA3: U1.1 (PA3); also elsewhere on the board
/PA4: U1.2 (PA4); also elsewhere on the board
/PA5: U1.3 (PA5); also elsewhere on the board
/PA6: U1.4 (PA6); also elsewhere on the board
/PA7: U1.5 (PA7); also elsewhere on the board
/PB0: U1.6 (PB0); also elsewhere on the board
/PB1: U1.7 (PB1); also elsewhere on the board
/PB2: U1.8 (PB2); also elsewhere on the board
/PB3: U1.9 (PB3); also elsewhere on the board
/PB4: J2.6, U1.10 (PB4); also elsewhere on the board
/PB5: J2.10, U1.11 (PB5); also elsewhere on the board
/PB6: J2.2, U1.12 (PB6); also elsewhere on the board
/PB7: J2.4, U1.13 (PB7); also elsewhere on the board
/PC0: U1.16 (PC0); also elsewhere on the board
/PC1: U1.17 (PC1); also elsewhere on the board
/PC2: U1.18 (PC2); also elsewhere on the board
/PC3: U1.19 (PC3); also elsewhere on the board
/PC4: U1.20 (PC4); also elsewhere on the board
/PC5: U1.21 (PC5); also elsewhere on the board
/PC6: U1.22 (PC6); also elsewhere on the board
/PC7: U1.23 (PC7); also elsewhere on the board
/PD0: U1.26 (PD0); also elsewhere on the board
/PD1: U1.27 (PD1); also elsewhere on the board
/PD2: U1.28 (PD2); also elsewhere on the board
/PD3: U1.29 (PD3); also elsewhere on the board
/PD4: U1.30 (PD4); also elsewhere on the board
/PD5: U1.31 (PD5); also elsewhere on the board
/PD6: JP2.3 (B); also elsewhere on the board
/PD7: JP1.3 (B); also elsewhere on the board
/PDI_DATA: J3.1, U1.56 (PDI)
/PE0: U1.36 (PE0); also elsewhere on the board
/PE1: U1.37 (PE1); also elsewhere on the board
/PE2: U1.38 (PE2); also elsewhere on the board
/PE3: U1.39 (PE3); also elsewhere on the board
/PE4: U1.40 (PE4); also elsewhere on the board
/PE5: U1.41 (PE5); also elsewhere on the board
/PF0: U1.46 (PF0); also elsewhere on the board
/PF1: U1.47 (PF1); also elsewhere on the board
/PF2: U1.48 (PF2); also elsewhere on the board
/PF3: U1.49 (PF3); also elsewhere on the board
/PF4: U1.50 (PF4); also elsewhere on the board
/PF6: U1.54 (PF6); also elsewhere on the board
/PF7: U1.55 (PF7); also elsewhere on the board
/VBAT: U1.51 (VBAT); also elsewhere on the board
/~RESET: C8.2, J2.5, J3.5, R1.2, SW1.3 (K), SW1.4 (A), U1.57 (RESET/PDI)
GND: C1.1, C2.1, C3.1, C4.1, C5.1, C6.1, C7.1, C8.1, C9.1, C10.1, C11.1, C12.1, C13.1, J1.5 (GND), J2.1, J2.9, J3.6, R2.1, SW1.1, SW1.2, U1.14 (GND_2), U1.24 (GND_3), U1.34 (GND_4), U1.44 (GND_5), U1.52 (GND_6), U1.60 (GND), Y2.2, Y2.4; also elsewhere on the board
unnamed: JP1.2 (C), U1.33 (PD7)
unnamed: JP2.2 (C), U1.32 (PD6)
unnamed: C11.2, U1.58 (PR0), Y2.3
unnamed: C12.2, U1.59 (PR1), Y2.1
unnamed: C9.2, U1.43 (TOSC1), Y1.1
unnamed: C10.2, U1.42 (TOSC2), Y1.2
SHIELD: C13.2, J1.6 (SHIELD), R2.2

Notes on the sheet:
Kondensatory odsprzęgające pinów zasilających MCU
Złącze USB
Zasilanie części analogowej MCU
Złącze programujące PDI
Złącze programujące JTAG
Wybór połączenia PD6- PD7: USB/GPIO
Rezonator RTC
Rezonator CPU

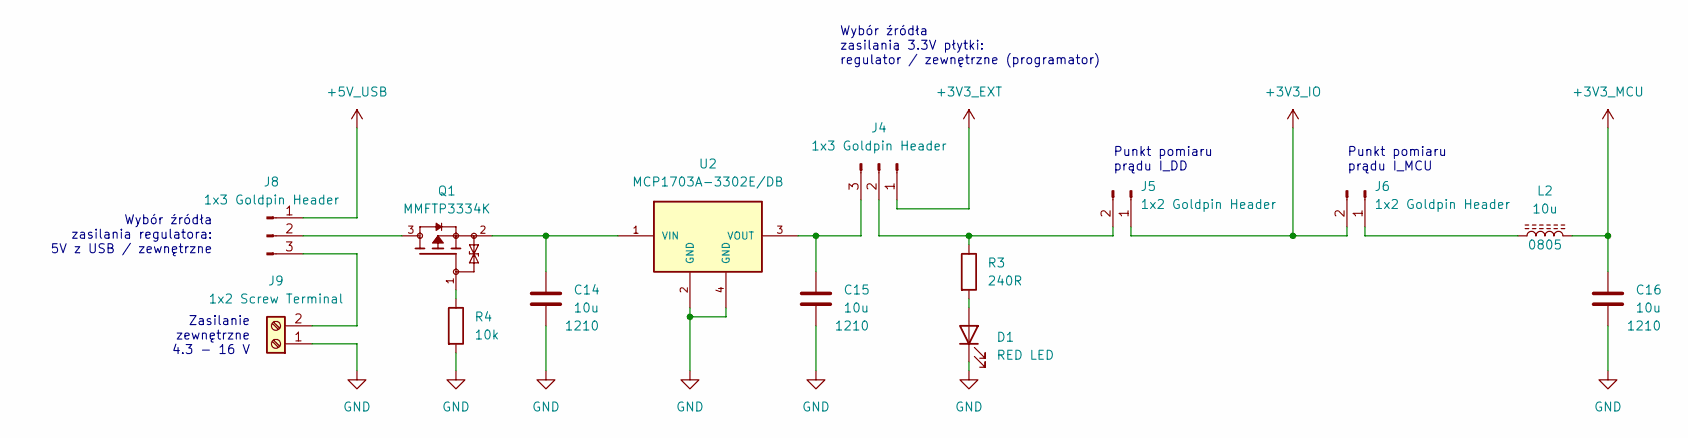
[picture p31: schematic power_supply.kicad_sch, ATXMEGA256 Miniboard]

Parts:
C14, C15, C16: 10u; C_1210_3225Metric_Pad1.33x2.70mm_HandSolder; Part Number C1210C106K4RAC
D1: RED LED; LED_0805_2012Metric_Pad1.15x1.40mm_HandSolder; Part Number LTST-C171KRKT
J4, J8: 1x3 Goldpin Header; PinHeader_1x03_P2.54mm_Vertical; Part Number DS1021-1X3SF182-B
J5, J6: 1x2 Goldpin Header; PinHeader_1x02_P2.54mm_Vertical; Part Number DS1021-1X2SF162-B
J9: 1x2 Screw Terminal; DG381-3.5-02P-13-00AH; Part Number DG381-3.5-02P-13-00AH
L2: 10u; L_0805_2012Metric_Pad1.05x1.20mm_HandSolder; Part Number MLZ2012M100HT000
Q1: MMFTP3334K; TRANS_MMFTP3334K; Part Number MMFTP3334K
R3: 240R; R_0805_2012Metric_Pad1.20x1.40mm_HandSolder; Part Number 0805S8J0241T5E
R4: 10k; R_0603_1608Metric_Pad0.98x0.95mm_HandSolder; Part Number 0603SAJ0103T5E
U2: MCP1703A-3302E/DB; SOT230P700X180-4N; Part Number MCP1703A-3302E/DB

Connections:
+3V3_EXT: J4.1; also elsewhere on the board
+3V3_IO: J5.1, J6.2; also elsewhere on the board
+3V3_MCU: C16.2, L2.2; also elsewhere on the board
+5V_USB: J8.1; also elsewhere on the board
GND: C14.1, C15.1, C16.1, D1.1 (K), J9.1, R4.2, U2.2 (GND), U2.4 (GND); also elsewhere on the board
unnamed: D1.2 (A), R3.2
unnamed: J4.2, J5.2, R3.1
unnamed: C15.2, J4.3, U2.3 (VOUT)
unnamed: J6.1, L2.1
unnamed: J8.2, Q1.3
unnamed: J8.3, J9.2
unnamed: Q1.1, R4.1
unnamed: C14.2, Q1.2, U2.1 (VIN)

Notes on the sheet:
Punkt pomiaru prądu I_MCU
Punkt pomiaru prądu I_DD
Wybór źródła zasilania regulatora: 5V z USB / zewnętrzne
Wybór źródła zasilania 3.3V płytki: regulator / zewnętrzne (programator)
Zasilanie zewnętrzne 4.3 - 16 V

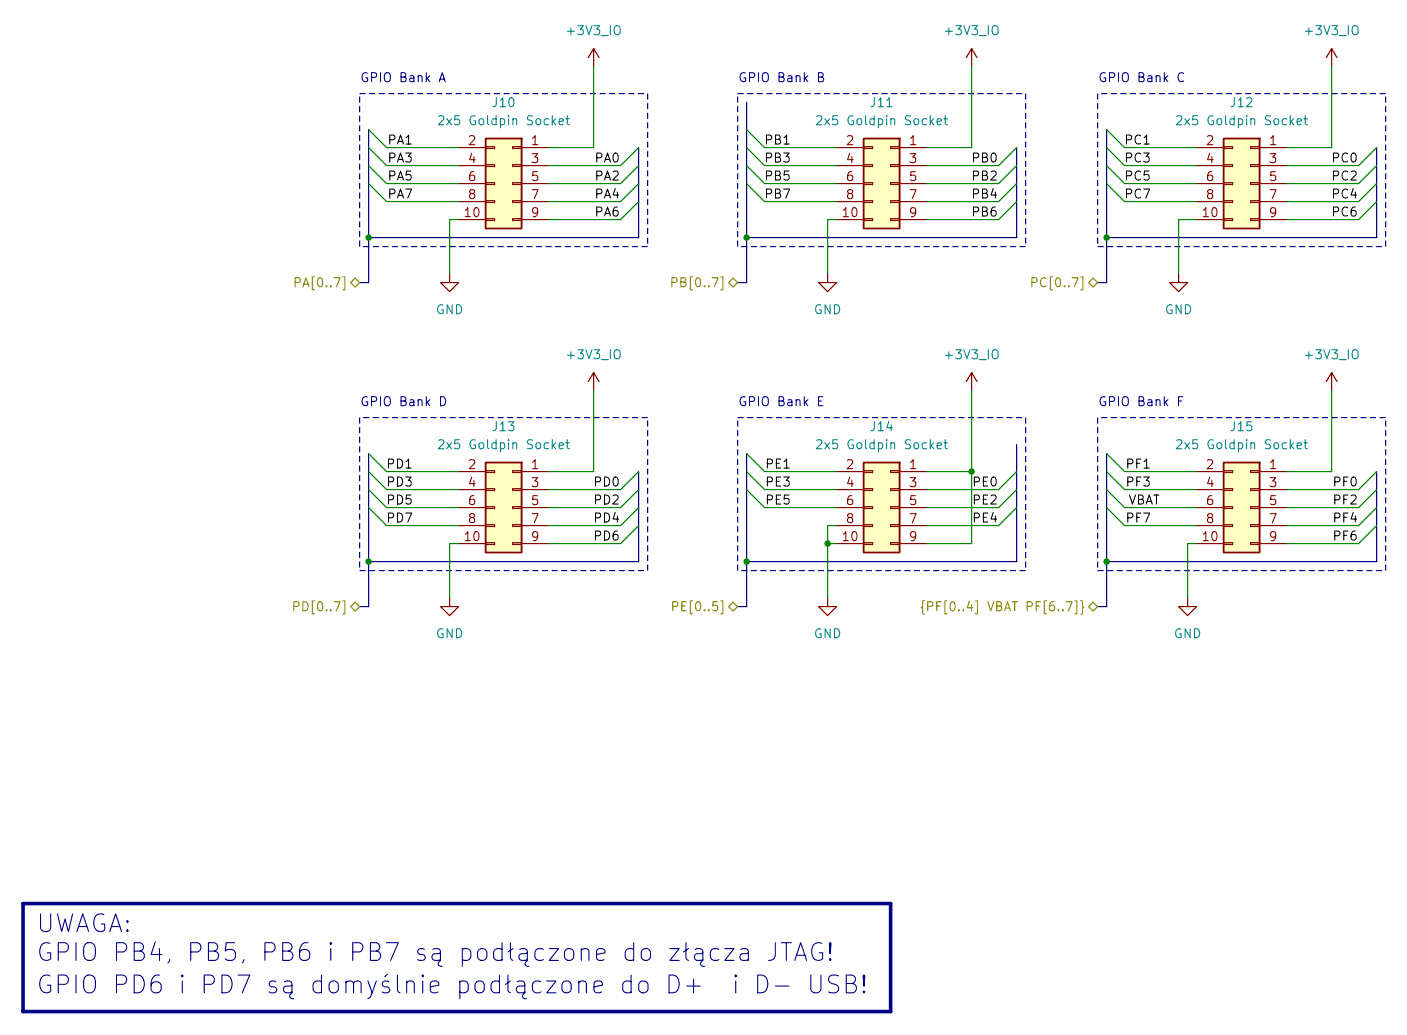
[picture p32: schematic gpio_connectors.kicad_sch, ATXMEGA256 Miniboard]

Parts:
J10, J11, J12, J13, J14, J15: 2x5 Goldpin Socket; PinSocket_2x05_P2.54mm_Vertical_SMD; Part Number ZL264-10DG

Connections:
+3V3_IO: J10.1, J11.1, J12.1, J13.1, J14.1, J14.9, J15.1; also elsewhere on the board
/PA0: J10.3; also elsewhere on the board
/PA1: J10.2; also elsewhere on the board
/PA2: J10.5; also elsewhere on the board
/PA3: J10.4; also elsewhere on the board
/PA4: J10.7; also elsewhere on the board
/PA5: J10.6; also elsewhere on the board
/PA6: J10.9; also elsewhere on the board
/PA7: J10.8; also elsewhere on the board
/PB0: J11.3; also elsewhere on the board
/PB1: J11.2; also elsewhere on the board
/PB2: J11.5; also elsewhere on the board
/PB3: J11.4; also elsewhere on the board
/PB4: J11.7; also elsewhere on the board
/PB5: J11.6; also elsewhere on the board
/PB6: J11.9; also elsewhere on the board
/PB7: J11.8; also elsewhere on the board
/PC0: J12.3; also elsewhere on the board
/PC1: J12.2; also elsewhere on the board
/PC2: J12.5; also elsewhere on the board
/PC3: J12.4; also elsewhere on the board
/PC4: J12.7; also elsewhere on the board
/PC5: J12.6; also elsewhere on the board
/PC6: J12.9; also elsewhere on the board
/PC7: J12.8; also elsewhere on the board
/PD0: J13.3; also elsewhere on the board
/PD1: J13.2; also elsewhere on the board
/PD2: J13.5; also elsewhere on the board
/PD3: J13.4; also elsewhere on the board
/PD4: J13.7; also elsewhere on the board
/PD5: J13.6; also elsewhere on the board
/PD6: J13.9; also elsewhere on the board
/PD7: J13.8; also elsewhere on the board
/PE0: J14.3; also elsewhere on the board
/PE1: J14.2; also elsewhere on the board
/PE2: J14.5; also elsewhere on the board
/PE3: J14.4; also elsewhere on the board
/PE4: J14.7; also elsewhere on the board
/PE5: J14.6; also elsewhere on the board
/PF0: J15.3; also elsewhere on the board
/PF1: J15.2; also elsewhere on the board
/PF2: J15.5; also elsewhere on the board
/PF3: J15.4; also elsewhere on the board
/PF4: J15.7; also elsewhere on the board
/PF6: J15.9; also elsewhere on the board
/PF7: J15.8; also elsewhere on the board
/VBAT: J15.6; also elsewhere on the board
GND: J10.10, J11.10, J12.10, J13.10, J14.8, J14.10, J15.10; also elsewhere on the board

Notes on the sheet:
GPIO Bank E
GPIO Bank F
GPIO Bank B
GPIO Bank D
GPIO PD6 i PD7 są domyślnie podłączone do D+ i D- USB!
GPIO PB4, PB5, PB6 i PB7 są podłączone do złącza JTAG!
UWAGA:
GPIO Bank A
GPIO Bank C

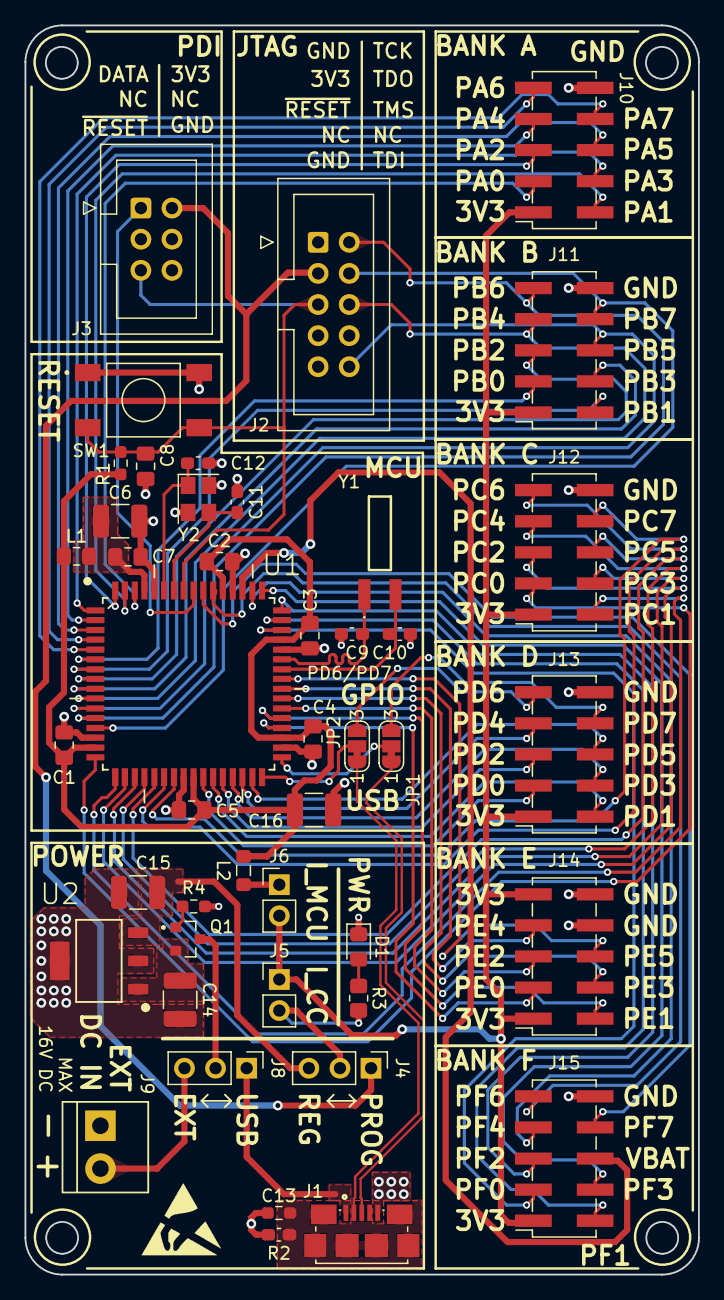
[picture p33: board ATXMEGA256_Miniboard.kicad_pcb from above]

Board: 4 copper layers, 55.0 x 102.0 mm, 45 parts (0 on the bottom side), 71 nets.

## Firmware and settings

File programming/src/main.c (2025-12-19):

/*
******************************************
Project:              
Board Revision: 1.0             
Application Version: 1.0          
Date:                 
Author:               
******************************************

Description:


LICENCE:


*/

// Includes
#include "main.h"


// Defines

// Function prototypes

// Global variables

// Interrupts
ISR(PORTA_INT0_vect) {
    // Reset interrupt flag
    PORTA.INTFLAGS = 0;
}
// Main loop
int main(void) {

    // External crystal clock
    OSC.XOSCCTRL = OSC_FRQRANGE_12TO16_gc | OSC_XOSCSEL_XTAL_16KCLK_gc;
    OSC.CTRL |= 0b00001000;
    while (!(OSC.STATUS & OSC_XOSCRDY_bm));
    _PROTECTED_WRITE(CLK.CTRL, CLK_SCLKSEL_XOSC_gc);
    OSC.CTRL &= ~OSC_RC2MEN_bm;

    // Power-down sleep mode
    SLEEP.CTRL = (SLEEP_SMODE_PDOWN_gc) | (SLEEP_SEN_bm);
   
    unsigned int a = 0;
    PORTD.DIR = 0xFF;
    PORTD.OUT = 0x00;

    PMIC.CTRL |= 0b00000111;
    PORTA.DIR = 0x00;
    PORTA.INTCTRL = 0b00000011;
    PORTA.INT0MASK = 0b00000100;
    PORTA.PIN2CTRL |= (PORT_OPC_PULLUP_gc) | (PORT_ISC_FALLING_gc);

    // Enable interrupts
    sei();

    while(1) {
        PORTD.OUT = 0x00;
        _delay_ms(500);
        PORTD.OUT = 0xFF;
        a++;
        __asm__ __volatile__ ( "sleep" "\n\t" :: );
    }

    return 0;
}

// Functions

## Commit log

2024-03-16 pushing the project to github for the first time
    [pcb.PcbDoc, quick_schematic.SchDoc, speed_devboard.PrjPcb]
2024-03-16 layout done poorly, but at least somewhat done
    [pcb.PcbDoc, quick_schematic.SchDoc]
2024-03-17 fixed ground planes, ready for review
    [pcb.PcbDoc, quick_schematic.SchDoc]
2024-03-17 changed headers, fixed ground planes
    [pcb.GBL, pcb.GBO, pcb.GBP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]
2024-03-17 Janusz chcial 0.5mm niepotrzebnejk sciezki
    [pcb.PcbDoc, quick_schematic.SchDoc]
2024-03-17 done fixes after first review
    [pcb.PcbDoc, quick_schematic.SchDoc, speed_devboard.PrjPcb]
2024-03-19 printing file
2024-03-19 quick fix, better pdf
    [pcb.PcbDoc]
2024-03-19 made smaller via holes as markers
    [pcb.PcbDoc, quick_schematic.SchDoc]
2024-03-19 gnd fix, and 3v3 connection fix
    [pcb.PcbDoc]
2024-03-19 small gnd changes
    [pcb.PcbDoc]
2024-03-19 fixed Janusz's fixes
    [pcb.PcbDoc]
2024-03-19 it works now, plz dont touch it anymore
    [pcb.PcbDoc]
2024-03-19 changed tht connector hole sizes
    [pcb.PcbDoc]
2024-05-24 fixed ldo footprint
    [pcb.PcbDoc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]
2025-03-20 pierwsza wersja bez nazw i footprintów
    [ATXMEGA256_Miniboard.kicad_sch]
2025-03-20 gotowe połączenia oprócz JTAG i kwarców
    [ATXMEGA256_Miniboard.kicad_pcb, ATXMEGA256_Miniboard.kicad_sch]
2025-03-20 poprawka ścieżek do bibliteki
    [ATXMEGA256_Miniboard.kicad_sch]
2025-03-22 usb + udokumentowanie elementów
    [ATXMEGA256_Miniboard.kicad_pcb, ATXMEGA256_Miniboard.kicad_sch]
2025-03-22 poprawka nazwy headera
    [ATXMEGA256_Miniboard.kicad_sch]
2025-03-22 przycisk zmieniony na smd
    [ATXMEGA256_Miniboard.kicad_pcb, ATXMEGA256_Miniboard.kicad_sch]
2025-03-27 led + złącze masy + złącze śrubowe (do opisania)
    [ATXMEGA256_Miniboard.kicad_sch, power_supply.kicad_sch]
2025-03-29 poprawka estetyczna zasilania
    [ATXMEGA256_Miniboard.kicad_sch, power_supply.kicad_sch]
2025-03-30 schemat rev. 1.0
    [ATXMEGA256_Miniboard.csv, ATXMEGA256_Miniboard.kicad_sch, power_supply.kicad_sch]
2025-04-01 optymalizacja BOM + pdf schematu
    [ATXMEGA256_Miniboard.csv, ATXMEGA256_Miniboard.kicad_sch, power_supply.kicad_sch]
2025-04-06 aktualizacja zlacza usb
    [ATXMEGA256_Miniboard.csv]
2025-04-19 rev 1.1
    [ATXMEGA256_Miniboard.csv, ATXMEGA256_Miniboard.kicad_sch, gpio_connectors.kicad_sch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]
2025-05-13 pdated parts on PCB from schematic, migrated to kicad 9
    [ATXMEGA256_Miniboard.kicad_pcb, ATXMEGA256_Miniboard.kicad_sch, gpio_connectors.kicad_sch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]
2025-05-25 PCB layout
    [ATXMEGA256_Miniboard_v2.kicad_pcb]
2025-06-26 Poprawki zasilania, zmiana oscylatora RTC, poprawki polaczen GPIO
    [ATXMEGA256_Miniboard.kicad_sch, gpio_connectors.kicad_sch, power_supply.kicad_sch]
2025-07-01 Zmiana zlacza PDI, dodany makefile i struktura plikow
    [ATXMEGA256_Miniboard.kicad_sch, fuses_dump_original.txt, gpio_connectors.kicad_sch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]
2025-07-16 layout komponentów
    [ATXMEGA256_Miniboard.kicad_pcb, ATXMEGA256_Miniboard.kicad_sch, gpio_connectors.kicad_sch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]
2025-07-19 wstepne poczenia
    [ATXMEGA256_Miniboard.kicad_pcb, ATXMEGA256_Miniboard.kicad_sch]
2025-07-27 layout rev 0.9, zegar do poprawy
    [ATXMEGA256_Miniboard.kicad_pcb]
2025-07-29 PCB Rev 1.0 + obrazki
    [ATXMEGA256_Miniboard-B_Cu.gbr, ATXMEGA256_Miniboard-B_Mask.gbr, ATXMEGA256_Miniboard-B_Paste.gbr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]
2025-07-29 update BOM, poprawki masy
    [ATXMEGA256_Miniboard-B_Cu.gbr, ATXMEGA256_Miniboard-B_Mask.gbr, ATXMEGA256_Miniboard-B_Paste.gbr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]
2025-08-23 Kicad v.9.99 + poprawa polaryzacji na silkscreen + dokumentacja PCB
    [ATXMEGA256_Miniboard-B_Cu.gbr, ATXMEGA256_Miniboard-B_Mask.gbr, ATXMEGA256_Miniboard-B_Paste.gbr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]
2025-08-31 dokumentacja HW
    [ATXMEGA256_Miniboard.kicad_pcb]
